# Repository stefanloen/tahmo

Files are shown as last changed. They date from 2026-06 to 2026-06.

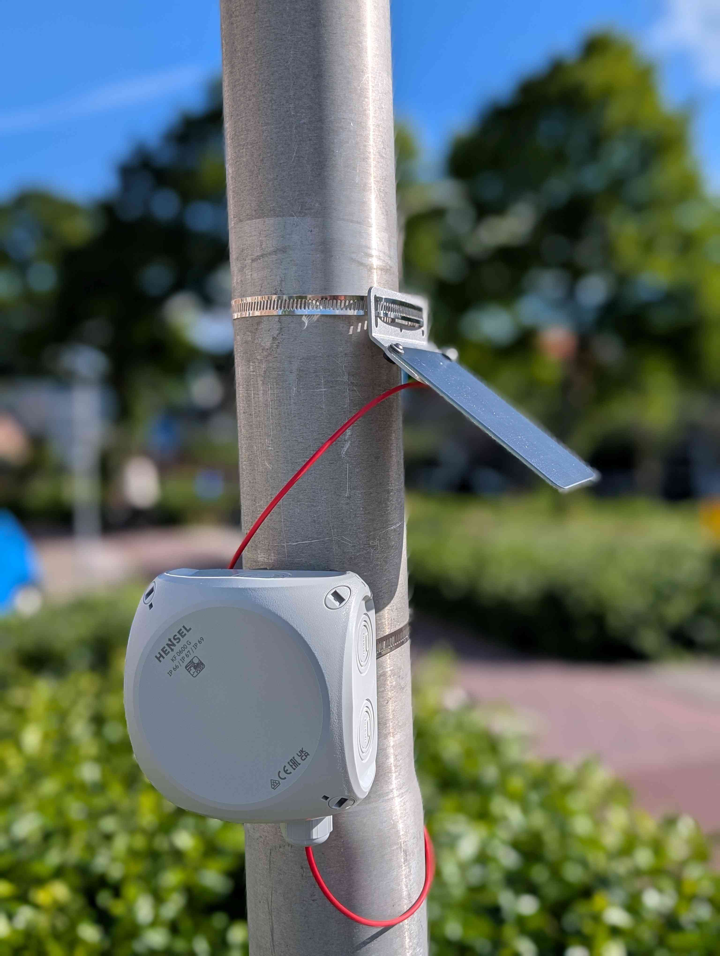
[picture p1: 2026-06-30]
docs/files/wlm.jpg

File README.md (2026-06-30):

# realtime-gnssrefl
The repository for the water level measurement system from TAHMO.

The project contains the following parts

## analysis
Provides tools for analysing GNSS date (similar to what is in the firmware).

## control
Contains the firmware for the Pico 2. For installation ensure Rust is installed and use the following commands
```bash
$ cd control
$ rustup target add thumbv8m.main-none-eabihf
```
And flash and run the firmware with the following commands:
```bash
$ cd control
$ cargo run --release
```

Creating an uf2 file:
```bash
$ picotool uf2 convert .\target\thumbv8m.main-none-eabihf\release\control -t elf control.uf2
```
## docs
Webpage tools for flashing, configuring, data viewing and documentation. Hosted at Github: [TAHMO WLM Dashboard](https://stefanloen.github.io/tahmo/)

## hardware
Contains the KiCAD PCB design files as raw project folder and as archive. Also contains some design documentation.

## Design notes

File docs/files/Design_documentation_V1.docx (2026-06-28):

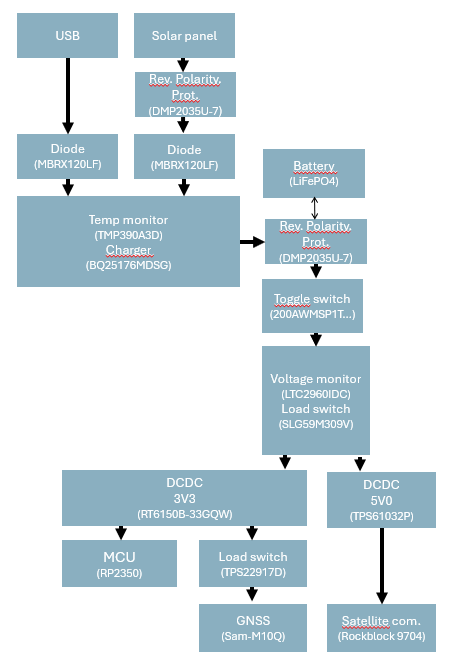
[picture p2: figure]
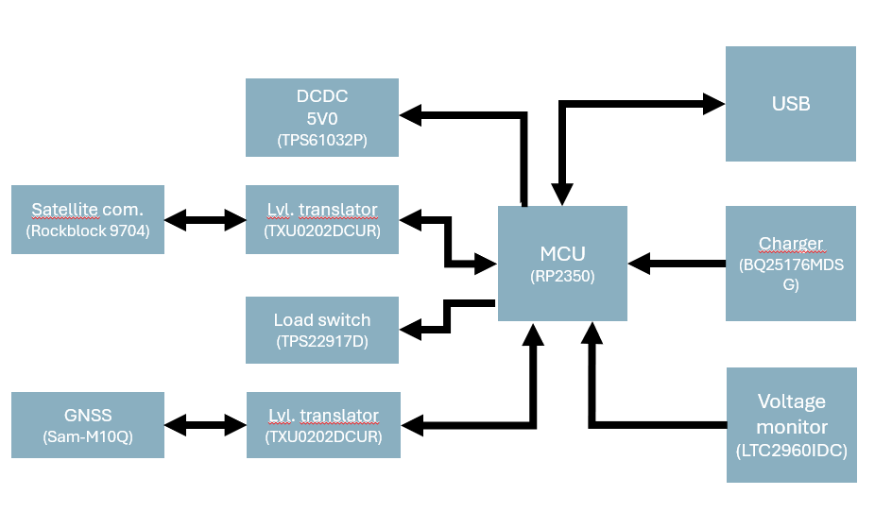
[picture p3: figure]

## Power management

### Battery

For the battery, LiFePO4 is chosen as it offers high temperature stability and long lifetime. LiFePO4 has a voltage range from 2.5V to 3.6V. A typical discharge curve looks like the following:

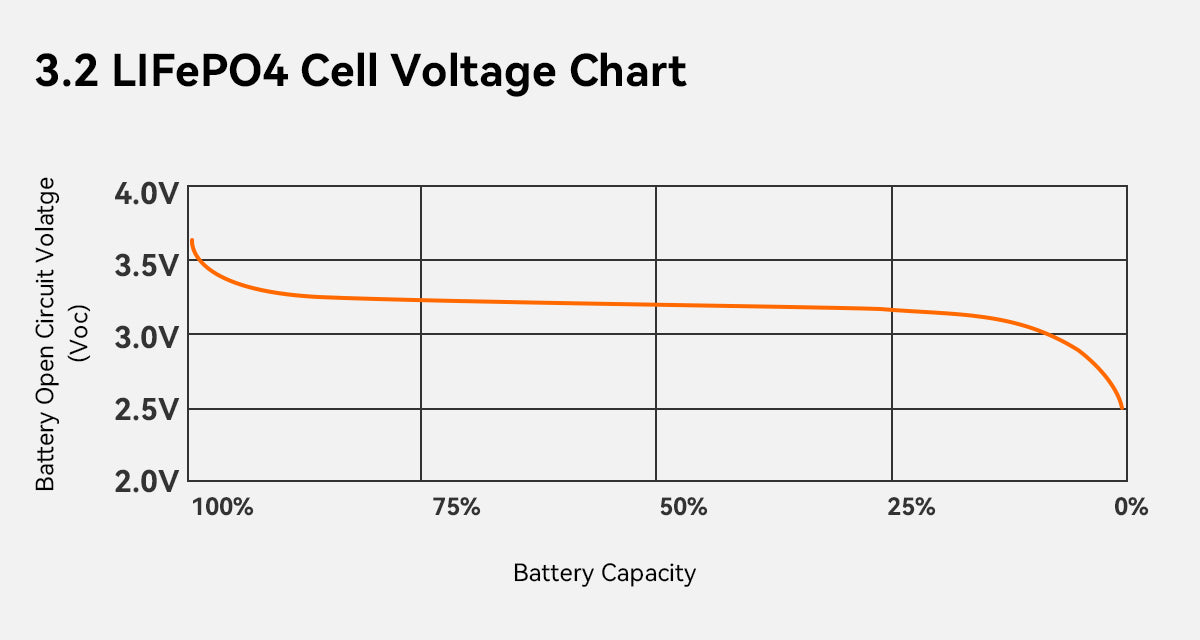
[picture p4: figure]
LiFePO4 battery voltage curve/ LFP charging curve

Battery size is 26550, which leads to roughly 3000mAh depending on manufacturer.

### Reverse polarity protector (Battery & solar panel)

To protect the system against a wrongly oriented battery, a P-channel enhancement mode mosfet is used. Inspiration from Reverse Voltage Protection With A P-FET | Hackaday (https://hackaday.com/2011/12/06/reverse-voltage-protection-with-a-p-fet/). The 5.1V Zener diode protects the gate against voltages above 5.1V. This is not necessary for battery protection, but it is for solar panel reverse voltage protection. Relevant specs are:

- Rds_on < 45mOhm (1A leads to 45mV drop, ~1% loss)
- Vgs_threshold = -0.7V (Lowest source goes is 2.5V – 1V body diode =1.5V)
- Vgs_breakdown = +-10V (Battery max is 3V6)
- Vds_breakdown = -20V (Battery max is 3V6)

Normal operation mode:

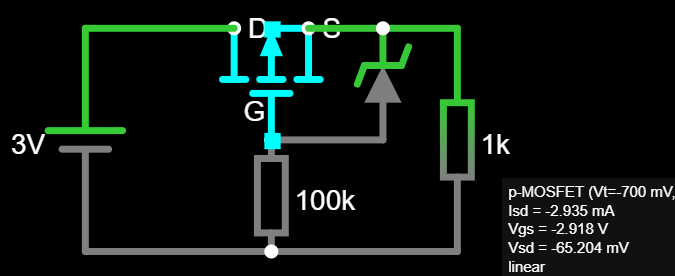
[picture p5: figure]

Reverse polarity:

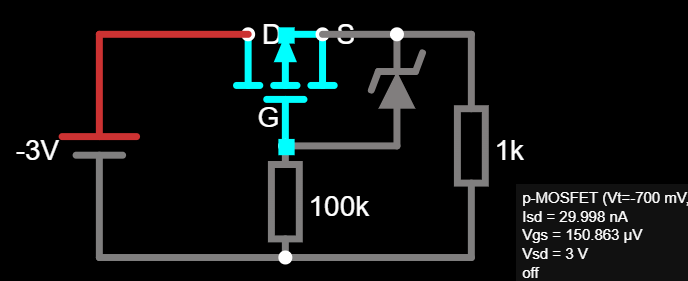
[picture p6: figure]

Charging:

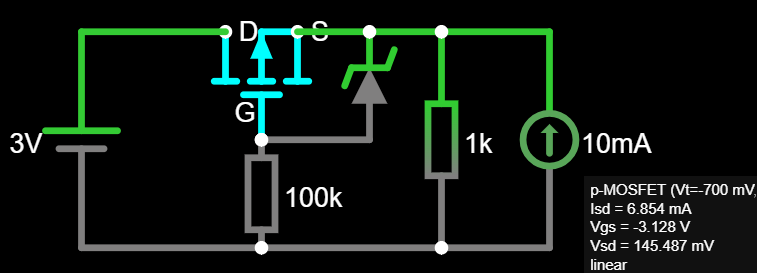
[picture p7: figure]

### Reverse polarity indicator (Battery & solar panel)

To indicate that the battery is placed in reverse polarity, we use a reverse placed LED with a resistor. Typical reverse breakdown voltage is 5V. This is good enough for battery. For solar panel, we need to use a ‘stronger’ diode in series. Inspired by: From the Q and A | Nuts & Volts Magazine (https://www.nutsvolts.com/questions-and-answers/diodes-in-series).

This design uses 1N4148W. Important specs are:

- Leakage current <1 uA
- Max Forward voltage = 1V
- Max Reverse voltage = 75V

Typical LED <0.1uA

Because the leakage current is different and unpredictable ,we need resistors in parallel to make sure the 1N4148 diode ‘carries’ all the voltage. For this we use Resistors in a higher order of magnitude so the leakage current of the diodes themselves is negligible.

10uA parallel resistors: R=U/I = 20V/10uA = 2Mohm. To give the 1N4148 90% of the voltage, we give it a parallel resistor of 1.8Mohm. The LED is given 200kOhm. Verified in Fallstad:

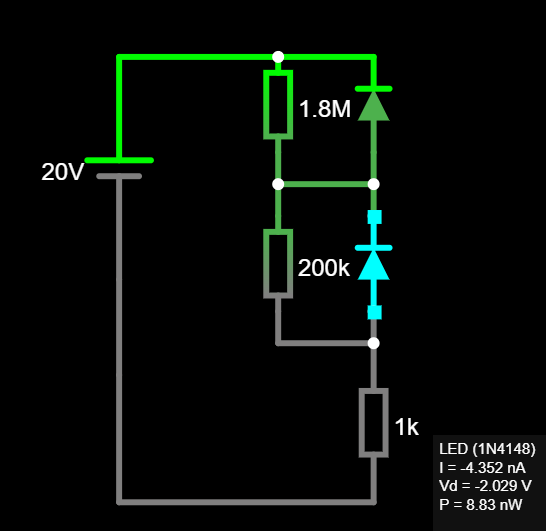
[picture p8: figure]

For practical reasons, 2.2Mohm and 220Kohm are used.

Led series resistance (18V-0.7V-0.7V)/3mA = 5.6k). A typical solar panel will give much lower current, but hopefully the LED will still be visible.

## Charging

The BQ25176M solar charger IC is used. It is particularly marketed for ‘solar harversting’ Important specifications are:

- Linear
- Battery tracking Input Voltage Dynamic Power Management (VINDPM)
- No timeout timer (Not needed)

Both solar panel and Vbus input are connected to input through a diode. MBRX120LF-TP is used. These have a ‘super low’ forward voltage drop of 0.2V. USB is open solderjumper because usb connected without battery plugged in is undefined behaviour of the BQ25176M. Caps are according to datasheet

ISET:

Icharge = 300 / Riset. 600Ohm → 500mA max charging current. With typical battery this is 0.15C.

VSET

100Kohm → 3.5V max charge voltage

/PG

Open drain Active low power good. It means the input voltage is OK. Connected to MCU. 10Kohm pullup according to datasheet. Open solderjumper to LED. R = (3.3V-0.7V) / 3mA ~= 1Kohm

STAT

Open drain Active low Charging status. 10Kohm pullup according to datasheet. Connected to MCU. Open solderjumper to LED. R = (3.3V-0.7V) / 3mA ~= 1Kohm

Bias

Bias pin is connected through 10kOhm to ground. Tolerance is unknown so 1% used. BIAS pin can be pulled down to disable charging. This is used for temperature monitoring of the battery. It is connected to the output of the programmable temperature switch TMP390A3D.

### TMP390A3D

Programmable temperature switch. Open drain active low outputs connected together. On both hot and cold trip the bias pin from the charger is pulled down. Output pins need 10kOhm pullup, but to not interfere with the bias resistor of the BQ25176M, it is not placed. This component is placed close to the GND of the batter for best heat transfer possible. 1 cap according to datasheet.

SET A

9.09 Kohm → 60 degrees hot trip

SET B

21.5 Kohm → 0 degrees cold trip. This also sets the hysteresis to 5% for both hot and cold trip.

## Undervoltage protection

After a toggle switch (200AWMSP1T2A1M2RE) a load switch (SLG59M309V) is placed to disconnect all power-draining components. If one of these switches in series is disconnected, charging via solar panel or USB still functions.

### SLG59M309V

On is connected to active low empty_bat. This is the signal coming from the voltage monitor (LTC2960IDC-1). 10nF capacitor on CAP pin → 2.5ms rise time.

### LTC2960IDC-1

Voltage monitor. Connected directly after the polarity protection. Quite specialized IC to configure programmable voltage thresholds (low battery & empty battery) and programmable hysteresis. 1 cap according to reference schematics

ADJ input below 400mV pulls RST low → open drain active low empty bat

IN+ input below 400mV pulls OUT low → open drain active low low bat

Low bat triggers at 0.4V / 49.9 x (340 + 49.9) = 3.13V

Empty bat is more complex. It has huge hysteresis to account for the voltage dip at the end of the LiFePO4 battery capacity. The 100K pull-up resistor on empty bat makes the circuit a bit more complex. Out / Lowbat does not have a pull-up resistor as this is already integrated into the MCU and performance is not critical. (So software mistake does not cause problems)

Falling threshold: 0.4V / 49.9 x (316 || (1.5M + 100k) + 49.9) = 2.51V

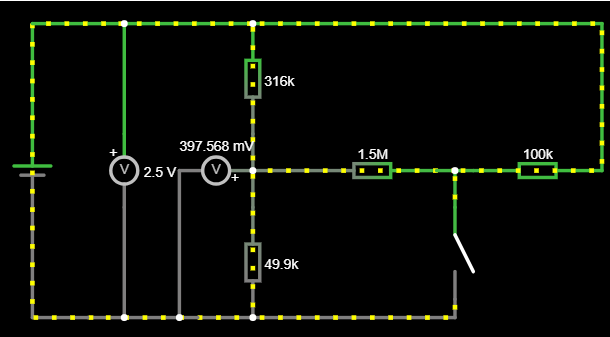
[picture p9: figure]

When empty bat is pulled low, the battery voltage must rise higher because the voltage divider used for the threshold is pulled down extra by the empty bat output. The internal hysteresis of 10mV in the voltage monitor IC is also taken into account.

Rising threshold: 0.4V / (49.9 || 1500) x ((49.9 || 1500) + 316)) = 3.09V

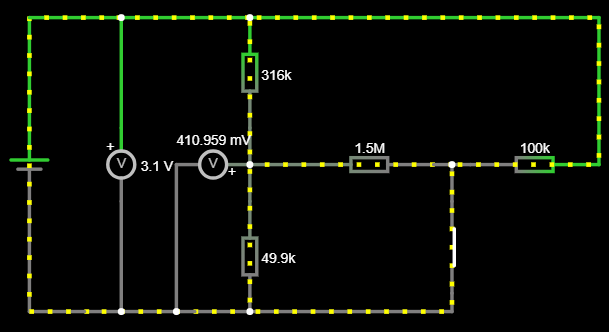
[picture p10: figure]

Values are found with Python Sympy.

RT

Connected to VCC for a 200ms reset timeout delay.

## 5V DCDC Boost convert

To create 5V from Vsys for the Rockblock, the TPS61032P is used. This seems a bit overkill, as it can supply 4A from 1.8V input. The Rockblock draws 500mA according to datasheet However, tests have shown (at least, the hypothesis is) that the input spike it draws is much higher. This caused problems in the prototype. Therefore, the 5V DCDC in this design is comfortably overkill.

For the inductor, CDRH124–6R8 is used according to datasheet (max power solution)

Vbat has 20uF cap (10uF is max power solution)

Output cap is 220uF tantalum low esr with a 2.2uF X5R capacitor (both from max power solution). An extra slot is available to double the capacitance if necessary.

LBI & LBO

Can be used for low battery indication. Unused. LBI is connected to GND as it cannot be left floating.

SYNC

Power save mode is disabled through Closed solderjumper by connecting SYNC to VSYS

TPS22917DBV

EN

Enables the DCDC. Connected to MCU. Pulled down with 100k

FB

Only used for adjustable versions. The TPS61032P is fixed at 5V

## 3V3 DCDC Buck boost converter

The RT6150B-33GQW creates 3V3 from the Vsys. It has to be buck boost as VSYS swings around 3V2. This DCDC is always on as it powers the mcu. Caps overspecced according to datasheet. Inductor according to datasheet.

FB

Connected to VOUT for non-adjustable versions

PS

Power save mode connected to GND through closed solderjumper to enable power save mode operation.

## GNSS load switch

To enable the GNSS, the SLG59M309V (Same as for battery undervoltage lockout) is used. Previously, the TPS22917 was used, but its replaced by this IC for the sole reason of less different components. Connections same as other SLG59M309V

## GNSS

The SAM-M10Q is used. This has also been used in the prototype. No requirements on caps.

Timepulse

Can be enabled by soldering the jumpersolder, this enables a blinking orange LED when GNSS signals are received. Max 2mA according to datasheet. R = (3.3V-0.7) / 2mA = 1.3kOhm. 2kOhm used.

EXTINT

No reason to use, but connected to MCU anyway with open solderjumper.

SAFEBOOT & RESET & SDA & SCL

Unused

RXD & TXD

Uart is used for communication with the MCU. Tests have show that the gnss is backpowered through UART when VCC is off. This is prevented by using a Level translator.

### Level translator

TXU0202DCUR is used to protect the gnss module (and the rockblock) against backpowering. Caps according to datasheet.

OE

Output enable. Enabled by the same signal that turns the load switch (or 5Vdcdc for rockblock) on, coming from the MCU. When disabled all outputs are isolated.

## Satellite communication

The rockblock 9704 is a standalone module that is used to connect with the Iridium network. The following pins are used:

I_EN

Enables the module

I_BTD

Signals to the MCU that the supercapacitor is charged

I_WK_I / I_WK_O

Unused but connected so MCU anyway for later wake functionality

TXD / RXD

Uart, also connected through TXU0202DCUR

## USB

USB-C connector is used. According to Universal Serial Bus Type-C Cable and

Connector Specification, release 2:

CC1 and CC2:

Need 5.1k pull-down (p. 236) 1% tolerance just to be sure

VBUS:

Max capacitance = 10uF (p. 234)

## MCU

The RP2350A is used. This was also used on the prototype with a Raspberry Pi Pico 2. All design according to schematic followed from Raspberry Pi Pico 2 Datasheet: An RP2350-based microcontroller board. (https://pip-assets.raspberrypi.com/categories/1005-raspberry-pi-pico-2/documents/RP-008299-DS-2-pico-2-datasheet.pdf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) Layout rules followed from this guideline: Hardware design with RP2350: Using RP2350 microcontrollers to build boards and products. (https://pip-assets.raspberrypi.com/categories/1214-rp2350/documents/RP-008280-DS-1-hardware-design-with-rp2350.pdf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)

Voltage regulator layout guidelines are strictly followed. AOTA-B201610S3R3-101-T Inductor is used.

### Watchdog

To enable low power savings and watchdog functionality, the TPL5010 is used. The configuration is in such a manner that it signals the MCU every ~60seconds. The MCU must respond with DONE. If the MCU fails to do so, it pulls the RST pin low which is connected to the RUN pin of the MCU. RST has a pullup. Cap according to spec.

Delay

The delay resistor is set to 22.1Kohm which corresponds to roughly 1 minute. This means the wake signal is given every minute. This way, it can also be used to sleep for 1 minute.

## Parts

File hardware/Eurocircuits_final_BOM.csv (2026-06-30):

Reference: | E1789734
Date: | Tue Jun 30 2026 15:51:00 GMT+0200 (Midden-Europese zomertijd)
Generated by: | Eurocircuits PCBA Visualizer
Reference designators | Quantity | MPN | Manufacturer | Description
C1, C2, C3, C4, C12, C13, C14, C15, C16, C18, C20, C22, C23, C26, C29 | 15 | GPC0603104-25 | Generic part | 0.1µF ±10% 25V Ceramic Capacitor X7R 0603 (1608 Metric)
C32, C33 | 2 | GPC0603104-25 | Generic part | 0.1µF ±10% 25V Ceramic Capacitor X7R 0603 (1608 Metric)
C5 | 1 | GPC0805106-25 | Generic part | 10µF ±10% 25V Ceramic Capacitor X5R 0805 (2012 Metric)
C6, C7 | 2 | GPC1210476-16 | Generic part | 47µF ±20% 16V Ceramic Capacitor X5R 1210 (3225 Metric)
C8 | 1 | GPC0805225-25-X7R | Generic part | 2.2µF ±10% 25V Ceramic Capacitor X7R 0805 (2012 Metric)
C11, C36 | 2 | GPC0603103 | Generic part | 10000pF ±10% 50V Ceramic Capacitor X7R 0603 (1608 Metric)
C17, C25, C31 | 3 | GPC0603475-10 | Generic part | 4.7µF ±10% 10V Ceramic Capacitor X5R 0603 (1608 Metric)
C19, C21, C24 | 3 | GPC0402475-6.3 | Generic part | 4.7µF ±20% 6.3V Ceramic Capacitor X5R 0402 (1005 Metric)
C27, C30 | 2 | GPC0603150 | Generic part | 15pF ±5% 50V Ceramic Capacitor C0G, NP0 0603 (1608 Metric)
C28 | 1 | GPC0603102-25 | Generic part | 1000pF ±10% 25V Ceramic Capacitor X7R 0603 (1608 Metric)
C34, C35 | 2 | GPC0603105 | Generic part | 1µF ±10% 50V Ceramic Capacitor X5R 0603 (1608 Metric)
R1 | 1 | GPR06032K | Generic part | 0603, Res 2.0kOhm, 75V, 1.0%, 100mW
R2, R3 | 2 | GPR06035K1 | Generic part | 0603, Res 5.1kOhm, 75V, 1.0%, 100mW
R4, R5, R17, R26, R32, R36 | 6 | GPR0603100K | Generic part | 0603, Res 100.0kOhm, 50V, 1.0%, 100mW
R37 | 1 | GPR0603100K | Generic part | 0603, Res 100.0kOhm, 50V, 1.0%, 100mW
R18, R19 | 2 | GPR0603100K | Generic part | 0603, Res 100.0kOhm, 50V, 1.0%, 100mW
R6, R7 | 2 | GPR060327R | Generic part | 0603, Res 27.0Ohm, 75V, 1.0%, 100mW
R8 | 1 | GPR040233R | Generic part | 0402, Res 33.0Ohm, 50V, 1.0%, 62.5mW
R9 | 1 | GPR0603200R | Generic part | 0603, Res 200.0Ohm, 50V, 1.0%, 100mW
R10 | 1 | GPR060322K | Generic part | 0603, Res 22.0kOhm, 50V, 1.0%, 100mW
R11, R12, R15, R35, R40, R41 | 6 | GPR06031K | Generic part | 0603, Res 1.0kOhm, 50V, 1.0%, 100mW
R16, R20 | 2 | GPR06031K | Generic part | 0603, Res 1.0kOhm, 50V, 1.0%, 100mW
R13, R14 | 2 | GPR0603100R | Generic part | 0603, Res 100.0Ohm, 50V, 1.0%, 100mW
R21 | 1 | GPR06039K1 | Generic part | 0603, Res 9.1kOhm, 75V, 1.0%, 100mW
R23 | 1 | GPR06032M2 | Generic part | 0603, Res 2.2MOhm, 75V, 1.0%, 100mW
R24 | 1 | GPR0603220K | Generic part | 0603, Res 220.0kOhm, 75V, 1.0%, 100mW
R25 | 1 | GPR06035K6 | Generic part | 0603, Res 5.6kOhm, 50V, 1.0%, 100mW
R31 | 1 | GPR06031M5 | Generic part | 0603, Res 1.5MOhm, 75V, 1.0%, 100mW
R33 | 1 | GPR0603620R | Generic part | 0603, Res 620.0Ohm, 75V, 1.0%, 100mW
R34 | 1 | GPR060310K | Generic part | 0603, Res 10.0kOhm, 50V, 1.0%, 100mW
R38, R39 | 2 | GPR060310K | Generic part | 0603, Res 10.0kOhm, 50V, 1.0%, 100mW
D1, D12 | 2 | LTST-C191KFKT | Lite-On | Orange 605nm LED Indication - Discrete 2V 0603 (1608 Metric)
D2, D6, D10 | 3 | LTST-C193KRKT-5A | Lite-On | Red 631nm LED Indication - Discrete 2V 0603
D3, D11 | 2 | LTST-C193KGKT-5A | Lite-On | Green 572nm LED Indication - Discrete 2V 0603 (1608 Metric)
D4 | 1 | LTST-C190TBKT | Lite-On | Blue 470nm LED Indication - Discrete 3.3V 0603 (1608 Metric)
D5 | 1 | 1N4148W | Vishay | Small Signal Fast Switching Diode SOD-123 SMD DIODE 75V /125mA
D7 | 1 | BZT52C5V6-7-F | Diodes Inc. | Zener Diode 5.6V 500mW ±7% Surface Mount SOD-123
J5 | 1 | 691213510002 | Wurth Elektronik | 2 Position Wire to Board Terminal Block Horizontal with Board 0.200" (5.08mm) Through Hole
L1 | 1 | 74479276222C | Wurth Elektronik | 2.2µH Shielded Molded Inductor 1.6A 135 mOhm Max 0806 (2016 Metric)
R28, R30 | 2 | RC0603FR-0749K9L | Yageo | RES 49.9K OHM 1% 1/10W 0603
BT1 | 1 | Keystone_1106 | Keystone Electronics | Battery Holder 26650 1 Cell SMD (SMT) Tab
C9 | 1 | TR3E227M016C0100 | Vishay Sprague | 220 µF ±20% Molded Tantalum Capacitors 16 V 2917 (7343 Metric) 100mOhm @ 100kHz
D8, D9 | 2 | MBR120LSFT1G | ON Semiconductor | Diode Schottky 20V 1A Surface Mount SOD-123L
IC1, IC2 | 2 | TXU0202DCUR | Texas Instruments | Two channel fixed-direction level shifter with channels in opposite direction 8-VSSOP -40 to 125
IC3 | 1 | RT6150B-33GQW | Richtek USA Inc. | Buck-Boost Switching Regulator IC Positive Fixed 3.3V 1 Output 800mA 10-WFDFN Exposed Pad
IC4 | 1 | TPS61032PWPR | Texas Instruments | Boost Switching Regulator IC Positive Fixed 5V 1 Output 3.6A (Switch) 16-PowerTSSOP (0.173", 4.40mm Width)
IC5, IC10 | 2 | SLG59M309V | Renesas | Power Switch/Driver 1:1 N-Channel 4A 8-FC-TDFN (1.5x2)
IC6 | 1 | RP2350A-CT | Raspberry Pi | MCU, 32 bit, ARM Cortex-M33F, 150 MHz, 520 KB RAM, QFN-60
IC7 | 1 | W25Q32RVXHJQ TR | Winbond Electronics | Serial NOR Flash, QSPI, 32MBit, 8-pin USON 2x3mm 133MHz
IC8 | 1 | LTC2960IDC-1#TRMPBF | Analog Devices | Supervisor Open Drain or Open Collector 2 Channel 8-DFN (2x2)
IC9 | 1 | TMP390A3DRLR | Texas Instruments | Thermostat Programmable Active Low Open Drain
J1 | 1 | ESW-108-58-S-D | Samtec | 16 Position Elevated Socket Connector 0.100" (2.54mm) Through Hole Gold
J2 | 1 | 2193200001 | Molex | USB-C (USB TYPE-C) USB 2.0 Receptacle Connector 24 (16+8 Dummy) Position Surface Mount, Through Hole
L2 | 1 | CDRH124NP-6R8MC | Sumida | 6.8 µH Shielded Inductor 4.9 A, ±20%, 23mOhm Max Nonstandard
L3 | 1 | AOTA-B201610S3R3-101-T | Abracon | 3.3 µH ±20% Shielded Molded Inductor 2.1 A 140mOhm Max 0806 (2016 Metric)
Q1, Q2 | 2 | DMP2035U-7 | Diodes Inc. | Transistor, P-Channel Enhancement Mode MOSFET, SMD
R22 | 1 | RMCF0603FT21K5 | Stackpole Electronics | 21.5 kOhms ±1% 0.1W, 1/10W Chip Resistor 0603 (1608 Metric) Automotive AEC-Q200 Thick Film
R27 | 1 | RT0603DRE07340KL | Yageo | 340 kOhms ±0.5% 0.1W, 1/10W Chip Resistor 0603 (1608 Metric) Thin Film
R29 | 1 | RMCF0603FT316K | Stackpole Electronics | 316 kOhms ±1% 0.1W, 1/10W Chip Resistor 0603 (1608 Metric) Automotive AEC-Q200 Thick Film
S1 | 1 | PTS810SJK250SMTRLFS | C&K Components | Tactile Switch SPST-NO Top Actuated Surface Mount
S2 | 1 | 200AWMSP1T2A1M2RE | E-Switch | Toggle Switch SPDT Through Hole
U1 | 1 | SAM-M10Q-00B | U-Blox | - RF Receiver Galileo, GLONASS, GPS 1.575GHz, 1.602GHz -165dBm 400kbps On-Board, Patch Module
U2 | 1 | TPL5010DDCR | Texas Instruments | Programmable Timer IC TSOT-23-6
U3 | 1 | BQ25176MDSGR | Texas Instruments | 800-mA linear battery charger for one-cell Li-ion and LiFePO4 with VINDPM 8-WSON -40 to 125
Y1 | 1 | ABM8-272-T3 | Abracon | 12 MHz ±30ppm Crystal 10 pF 50 Ohms 4-SMD, No Lead

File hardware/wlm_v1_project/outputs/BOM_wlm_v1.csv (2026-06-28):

Id | Designator | Footprint | Quantity | Designation | Supplier and ref
1 | BT1 | 26650_holder | 1 | Keystone 1106
2 | C1, C2, C3, C4, C12, C13, C14, C15, C16, C18, C20, C22, C23, C26, C29 | C_0603_1608Metric | 15 | 100n X5R 6.3V 10%
3 | C5 | C_0805_2012Metric | 1 | 22u X5R 16V 20%
4 | C6, C7 | C_1210_3225Metric | 2 | 47u X5R 10V 20%
5 | C8 | C_0805_2012Metric | 1 | 2u2 X5R 16V 10%
6 | C9 | CAPPM7343X430N | 1 | TR3E227M016C0100
7 | C11, C36 | C_0603_1608Metric | 2 | 10n X5R 10V
8 | C17, C25, C31 | C_0603_1608Metric | 3 | 4u7 6.3V X5R 20%
9 | C19, C21, C24 | C_0402_1005Metric | 3 | 4u7 6.3V X5R 20%
10 | C27, C30 | C_0603_1608Metric | 2 | 15p 25V C0G 5%
11 | C28 | C_0603_1608Metric | 1 | 1n X7R 25V 10%
12 | C32, C33 | C_0603_1608Metric | 2 | 100n X5R 10V
13 | C34, C35 | C_0603_1608Metric | 2 | 1uF X5R 35V
14 | D1, D12 | LED_0603_1608Metric | 2 | Led Orange 5mA
15 | D2, D6, D10 | LED_0603_1608Metric | 3 | Led Red 5mA
16 | D3, D11 | LED_0603_1608Metric | 2 | Led Green 5mA
17 | D4 | LED_0603_1608Metric | 1 | Led blue 5mA
18 | D5 | D_SOD-123 | 1 | 1N4148W
19 | D7 | D_SOD-123 | 1 | 5.6V Zener
20 | D8, D9 | SOD3716X135N | 2 | MBRX120LF-TP
21 | IC1, IC2 | SOP50P310X90-8N | 2 | TXU0202DCUR
22 | IC3 | SON50P250X250X80-11N-D | 1 | RT6150B-33GQW
23 | IC4 | SOP65P640X120-17N | 1 | TPS61032PWP
24 | IC5, IC10 | SLG59M309V | 2 | SLG59M309V
25 | IC6 | QFN40P700X700X90-61N-D | 1 | RP2350A-CT
26 | IC7 | SON50P300X200X40-9N | 1 | W25Q32RVXHJQ
27 | IC8 | SON45P200X200X80-9N-D | 1 | LTC2960IDC-1#TRMPBF
28 | IC9 | SOTFL50P160X60-6N | 1 | TMP390A3DRLR
29 | J1 | Rockblock_9704 | 1 | ESW-108-58-S-D
30 | J2 | 2193200001 | 1 | 219320-0001
31 | J5 | TerminalBlock_Phoenix_MKDS-1,5-2-5.08_1x02_P5.08mm_Horizontal | 1 | Screw_Terminal_01x02
32 | L1 | L_Wuerth_PMFI-201610 | 1 | 2u2 10% (74479276222C)
33 | L2 | CDRH124NP-6R8MC | 1 | CDRH124NP-6R8MC
34 | L3 | AOTAB201610S3R3101T | 1 | AOTA-B201610S3R3-101-T
35 | Q1, Q2 | DMP2035U7 | 2 | DMP2035U-7
36 | R1 | R_0603_1608Metric_Pad0.98x0.95mm_HandSolder | 1 | 2k 10%
37 | R2, R3 | R_0603_1608Metric_Pad0.98x0.95mm_HandSolder | 2 | 5.1k 1%
38 | R4, R5, R17, R26, R32, R36 | R_0603_1608Metric_Pad0.98x0.95mm_HandSolder | 6 | 100k 20%
39 | R6, R7 | R_0603_1608Metric_Pad0.98x0.95mm_HandSolder | 2 | 27R 50mW 1%
40 | R8 | R_0402_1005Metric_Pad0.72x0.64mm_HandSolder | 1 | 33R 63mW 1%
41 | R9 | R_0603_1608Metric_Pad0.98x0.95mm_HandSolder | 1 | 200R 63mW 1%
42 | R10 | R_0603_1608Metric_Pad0.98x0.95mm_HandSolder | 1 | 22k1 50mW 1%
43 | R11, R12, R15, R35, R40, R41 | R_0603_1608Metric_Pad0.98x0.95mm_HandSolder | 6 | 1k 10%
44 | R13, R14 | R_0603_1608Metric_Pad0.98x0.95mm_HandSolder | 2 | 100R 50mW 1%
45 | R16, R20 | R_0603_1608Metric_Pad0.98x0.95mm_HandSolder | 2 | 1k 50mW 1%
46 | R18, R19 | R_0603_1608Metric_Pad0.98x0.95mm_HandSolder | 2 | 100k 50mW 1%
47 | R21 | R_0603_1608Metric_Pad0.98x0.95mm_HandSolder | 1 | 9k09 1% 100 ppm/°C
48 | R22 | R_0603_1608Metric_Pad0.98x0.95mm_HandSolder | 1 | 21k5 1% 100 ppm/°C
49 | R23 | R_0603_1608Metric_Pad0.98x0.95mm_HandSolder | 1 | 2M2 20%
50 | R24 | R_0603_1608Metric_Pad0.98x0.95mm_HandSolder | 1 | 220k 20%
51 | R25 | R_0603_1608Metric_Pad0.98x0.95mm_HandSolder | 1 | 5k6 10%
52 | R27 | R_0603_1608Metric_Pad0.98x0.95mm_HandSolder | 1 | 340k 1%
53 | R28, R30 | R_0603_1608Metric_Pad0.98x0.95mm_HandSolder | 2 | 49k9 1%
54 | R29 | R_0603_1608Metric_Pad0.98x0.95mm_HandSolder | 1 | 316k 1%
55 | R31 | R_0603_1608Metric_Pad0.98x0.95mm_HandSolder | 1 | 1M5 1%
56 | R33 | R_0603_1608Metric_Pad0.98x0.95mm_HandSolder | 1 | 600R 1%
57 | R34 | R_0603_1608Metric_Pad0.98x0.95mm_HandSolder | 1 | 10k 1%
58 | R37 | R_0603_1608Metric_Pad0.98x0.95mm_HandSolder | 1 | 100k 1% <200 ppm/ºC
59 | R38, R39 | R_0603_1608Metric_Pad0.98x0.95mm_HandSolder | 2 | 10k 20%
60 | S1 | PTS810SJK250SMTRLFS | 1 | PTS810SJK250SMTR_LFS
61 | S2 | 200AWMSP1T2A1M2RE | 1 | 200AWMSP1T2A1M2RE
62 | U1 | ublox_SAM-M10Q | 1 | SAM-M10Q
63 | U2 | SOT-23-6 | 1 | TPL5010
64 | U3 | WSON_MDSGR_TEX | 1 | BQ25176MDSGR
65 | Y1 | ABM8272T3 | 1 | ABM8-272-T3

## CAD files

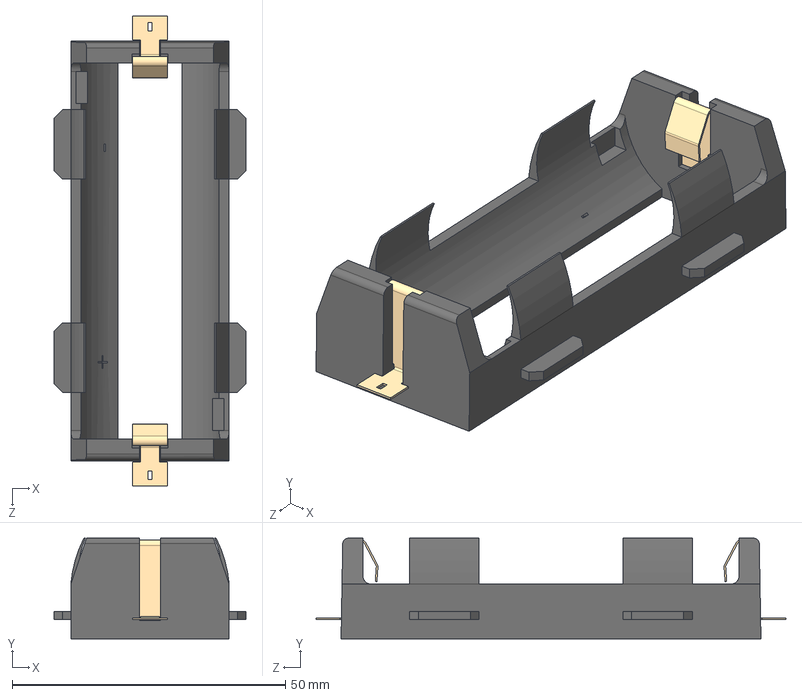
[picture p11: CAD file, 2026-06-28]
hardware/wlm_v1_project/3d_models/1106.stp
35.1 x 18.4 x 86.0 mm

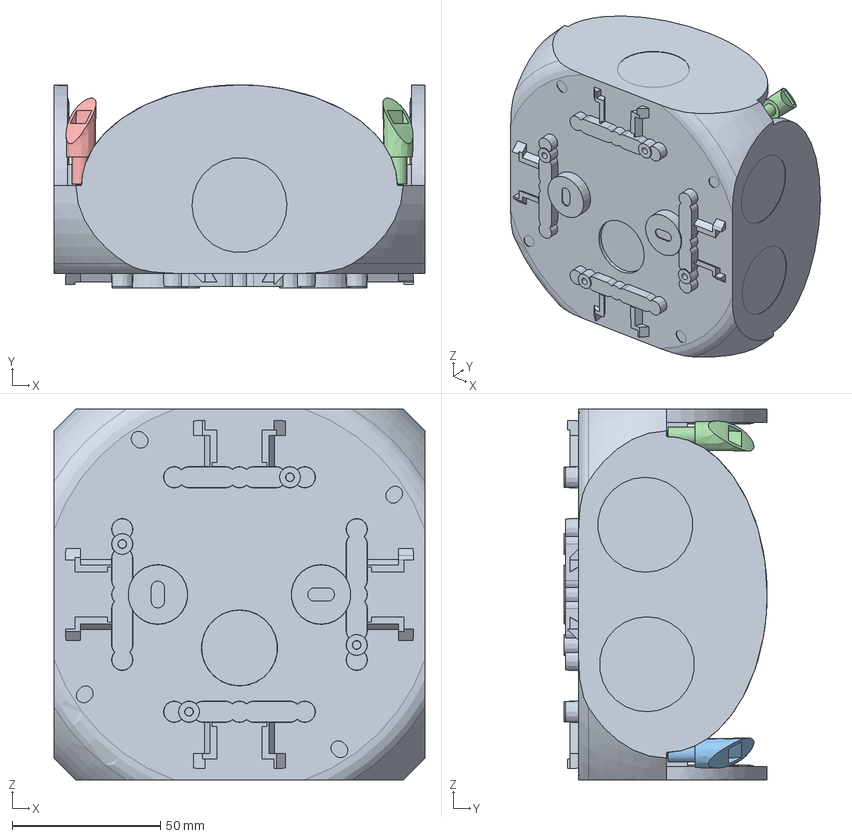
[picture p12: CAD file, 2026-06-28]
hardware/wlm_v1_project/freecad/Size_comparison.FCStd
125.0 x 68.5 x 125.0 mm
V_62520070_00
V_62520023_00
V_62520023_001
V_62520023_002
V_62520023_003
C_0603_1608Metric
PinHeader_1x01_P2.54mm_Vertical
C_0603_1608Metric001
BODY-SOT
C_0603_1608Metric002
LED_0603_1608Metric
R_0603_1608Metric
R_0603_1608Metric001
BODY-VSSOP
LEAD-VSSOP
LEAD-VSSOP001
LEAD-VSSOP002
LEAD-VSSOP003
LEAD-VSSOP004
LEAD-VSSOP005
LEAD-VSSOP006
LEAD-VSSOP007
R_0603_1608Metric002
AOTA-B201610S3R3-101-T
BODY-TSSOP
LEAD-TSSOP
LEAD-TSSOP001
LEAD-TSSOP002
LEAD-TSSOP003
LEAD-TSSOP004
LEAD-TSSOP005
LEAD-TSSOP006
LEAD-TSSOP007
LEAD-TSSOP008
LEAD-TSSOP009
LEAD-TSSOP010
LEAD-TSSOP011
LEAD-TSSOP012
LEAD-TSSOP013
LEAD-TSSOP014
LEAD-TSSOP015
DAP
ï¿½ï¿½1
ï¿½ï¿½2
ï¿½ï¿½003
C_0603_1608Metric003
ThermalPin
PinsArrayLR
PinsArrayLR001
PinsArrayLR002
PinsArrayLR003
PinsArrayLR004
PinsArrayLR005
PinsArrayLR006
PinsArrayLR007
PinsArrayLR008
PinsArrayLR009
R_0603_1608Metric003
R_0603_1608Metric004
C_0603_1608Metric004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

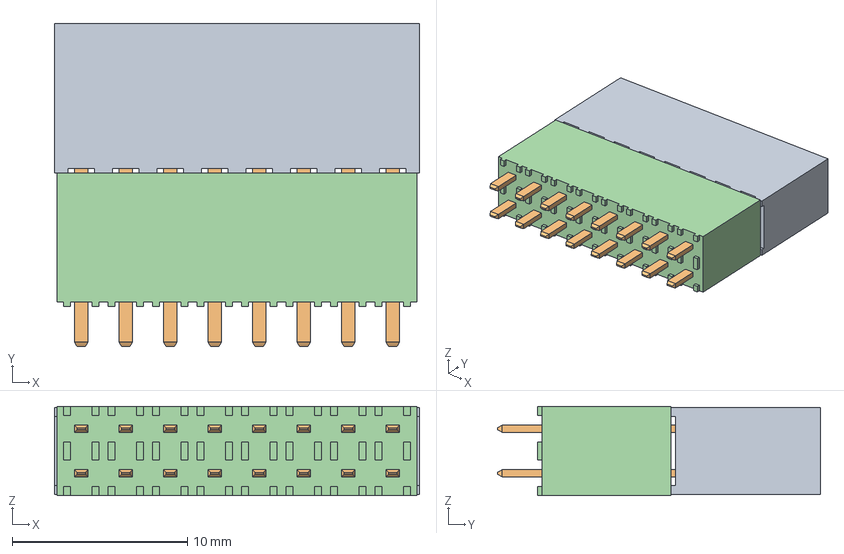
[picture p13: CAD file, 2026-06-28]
hardware/wlm_v1_project/3d_models/ESW-108-58-G-D.stp
20.8 x 18.4 x 5.08 mm
ESW-108-58-G-D_socket
ESW-108-58-G-D_pins
ESW-108-58-G-D2_PINS
ESW-108-58-G-D_bsocket

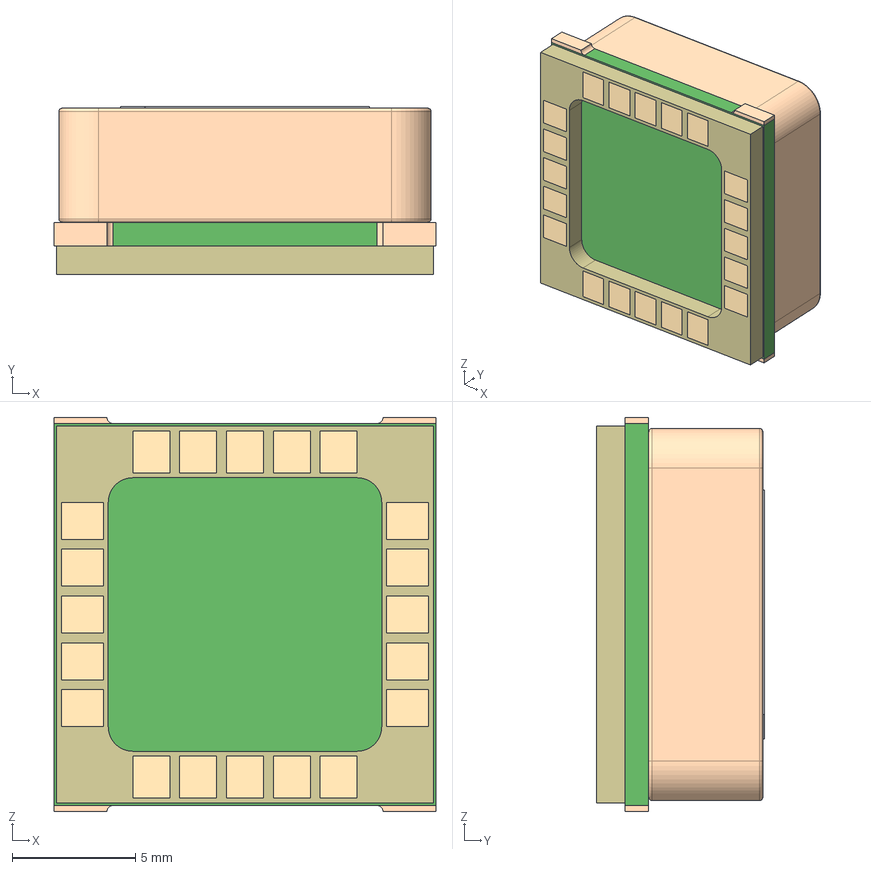
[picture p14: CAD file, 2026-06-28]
hardware/wlm_v1_project/3d_models/SAM-M10Q-00B_v1.step
15.5 x 6.80 x 16.0 mm

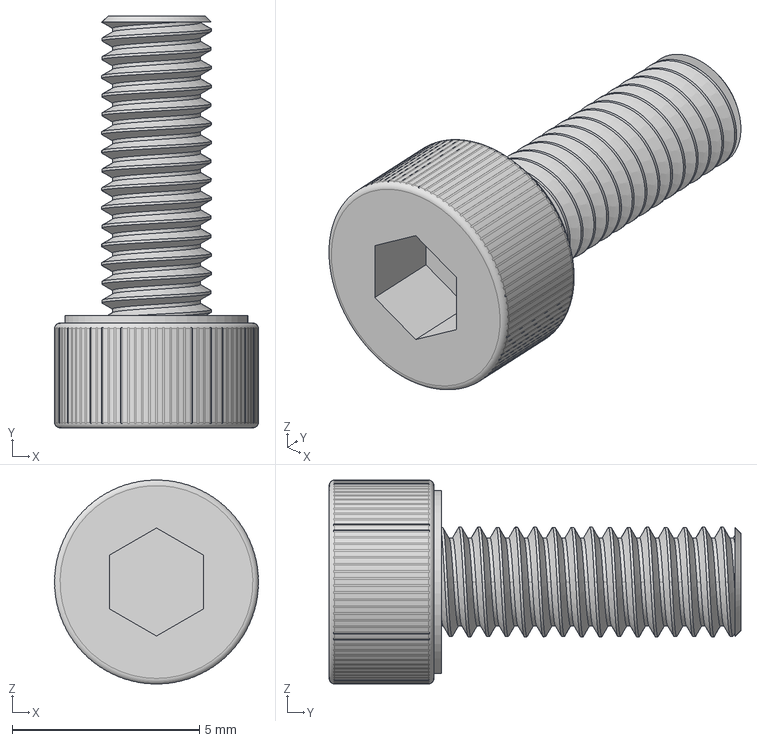
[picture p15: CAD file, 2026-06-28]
hardware/wlm_v1_project/3d_models/CHC M3 L8.step
5.45 x 11.0 x 5.45 mm

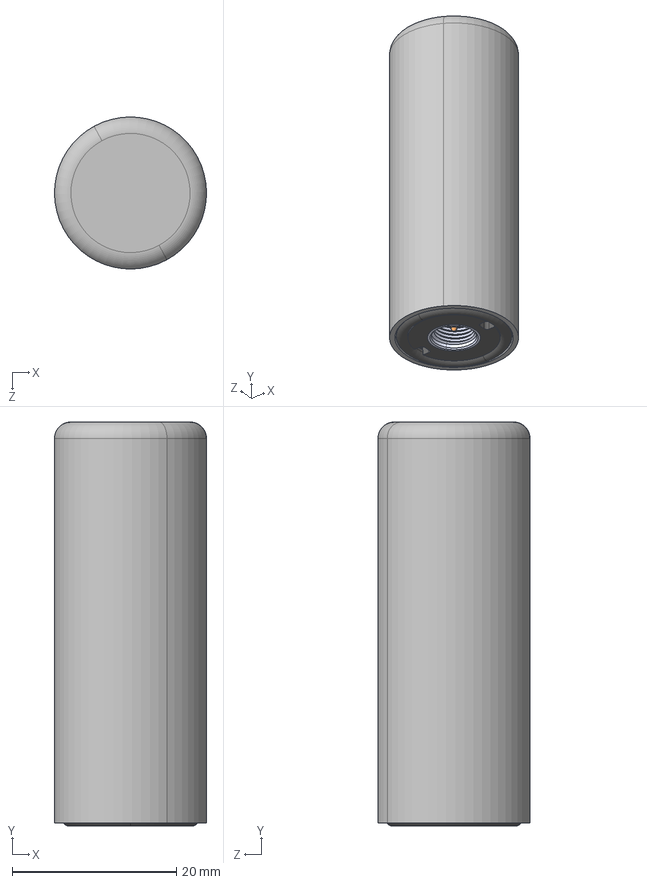
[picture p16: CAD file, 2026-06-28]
hardware/wlm_v1_project/3d_models/100-00003-02_RevB.STEP
18.5 x 49.2 x 18.5 mm
241-00003-05_View 1
178-00001-01_4.90mm LG x 4

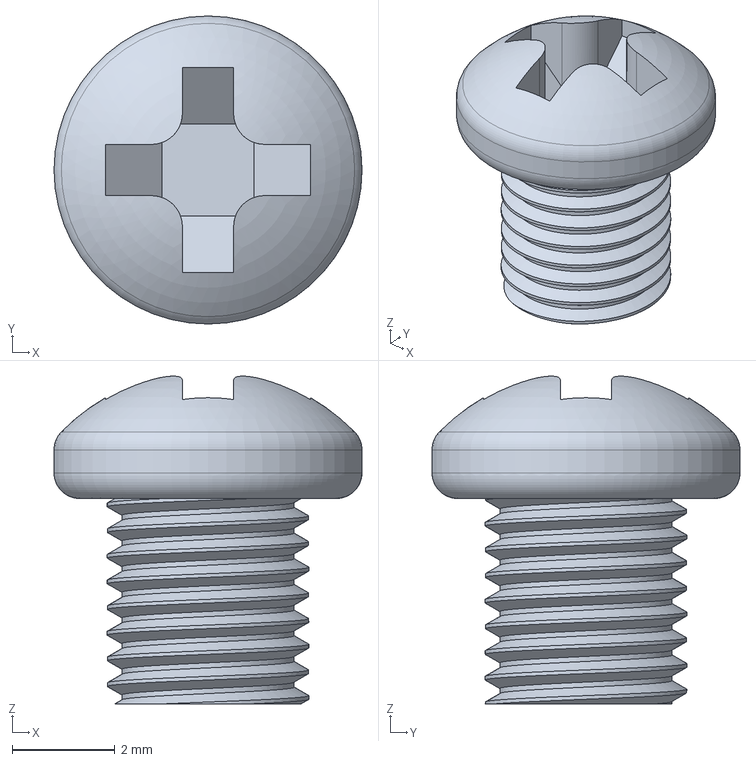
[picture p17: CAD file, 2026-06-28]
hardware/wlm_v1_project/3d_models/M4 x 4mm.step
6.00 x 6.00 x 6.38 mm

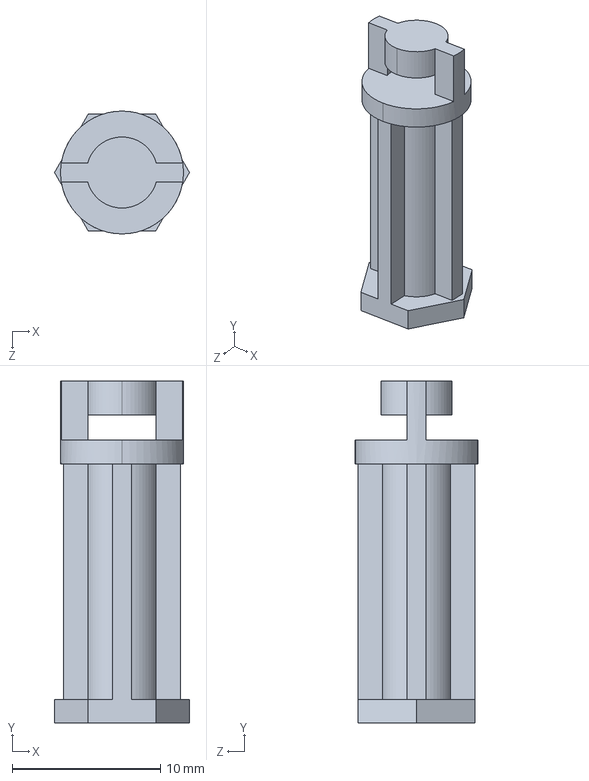
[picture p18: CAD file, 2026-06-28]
hardware/wlm_v1_project/3d_models/10035726.step
9.12 x 23.1 x 8.30 mm

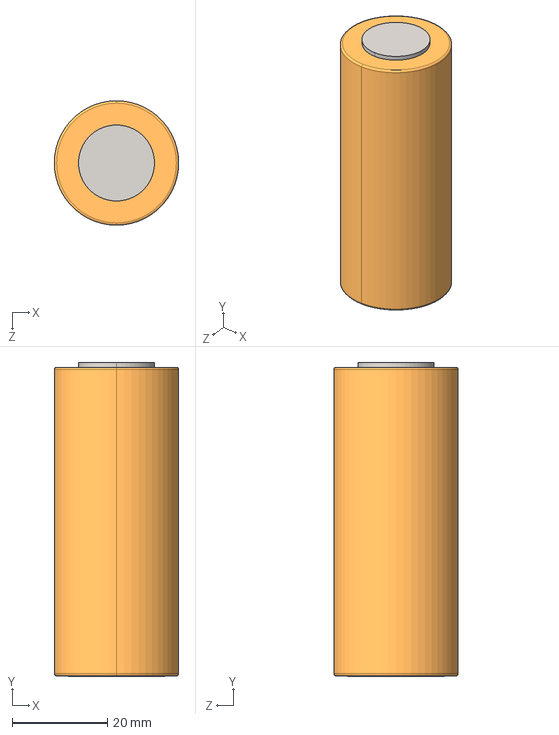
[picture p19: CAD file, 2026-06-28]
hardware/wlm_v1_project/3d_models/26650 Li-ion.STEP
26.2 x 66.1 x 26.2 mm

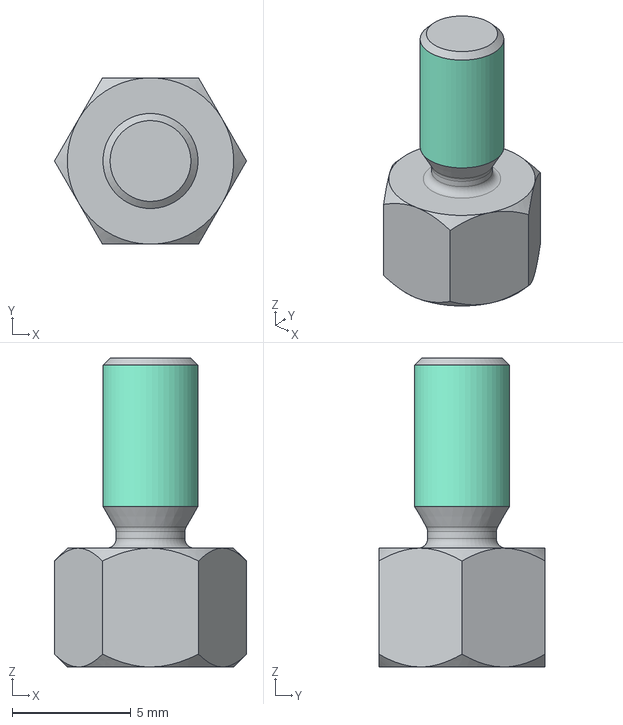
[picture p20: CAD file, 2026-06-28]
hardware/wlm_v1_project/3d_models/971050474.stp
8.08 x 7.00 x 13.0 mm

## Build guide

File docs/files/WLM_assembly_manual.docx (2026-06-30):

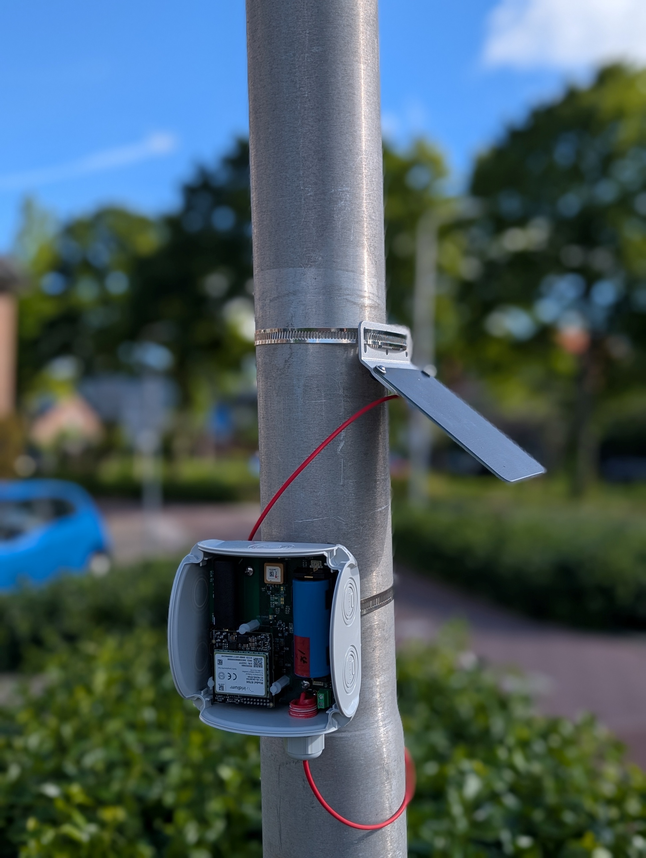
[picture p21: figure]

# WLM Assembly Manual

## TAHMO Water Level Monitor system

# Component overview

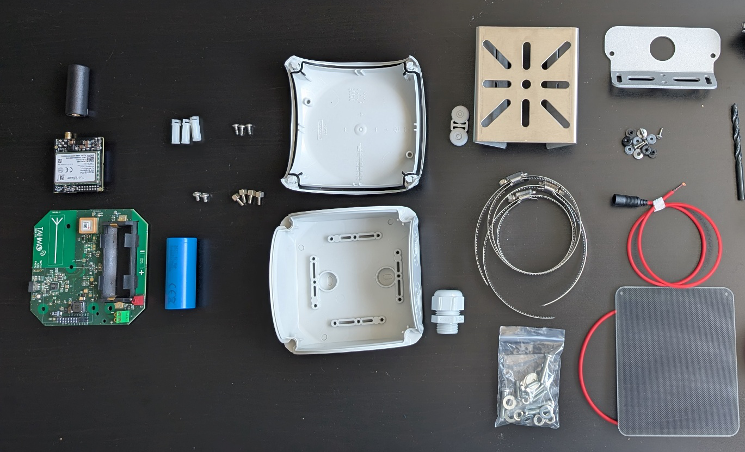
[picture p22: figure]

# Assembly WLM device

Remove one knockout.

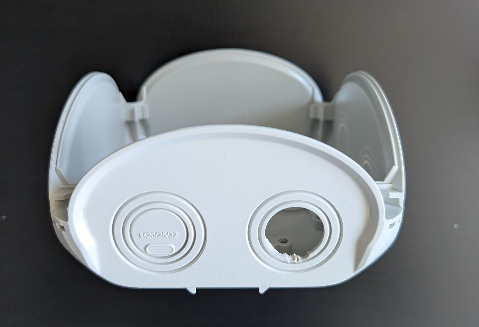
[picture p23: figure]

Drill 2 holes (green indicated) in the bottom, using 6mm drill bit. Also, bore out the holes indicated in red with 3.5mm.

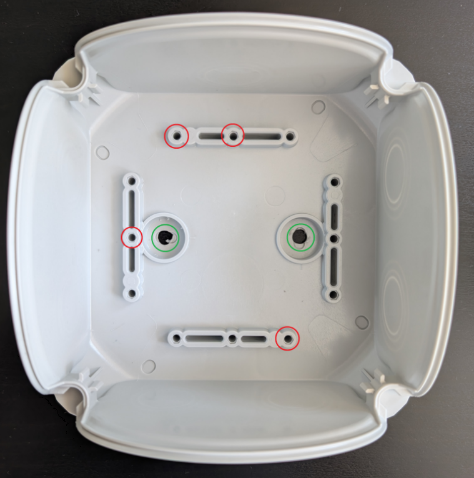
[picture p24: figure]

Screw the spacers in.

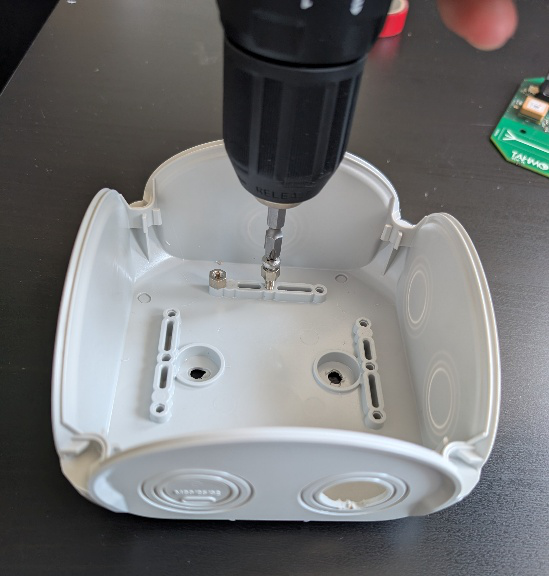
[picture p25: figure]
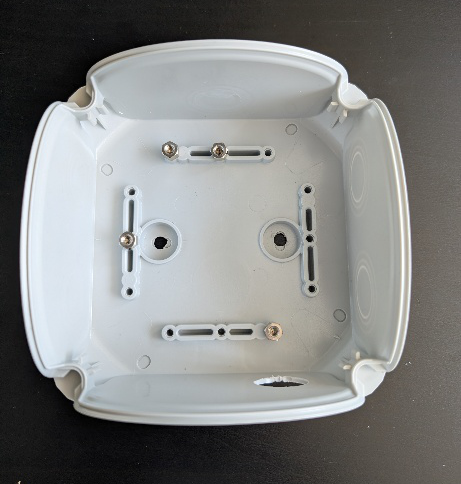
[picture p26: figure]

Mount the bracket using two bolts, washers and nuts.

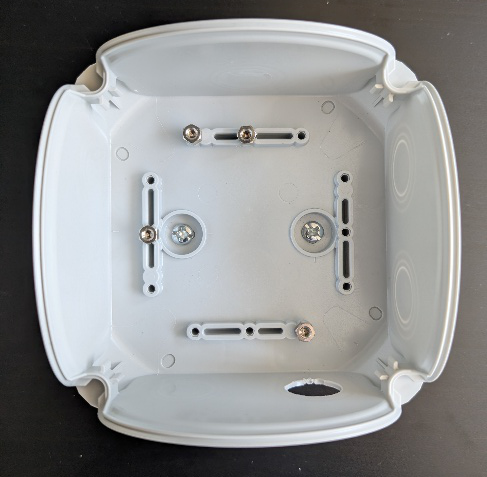
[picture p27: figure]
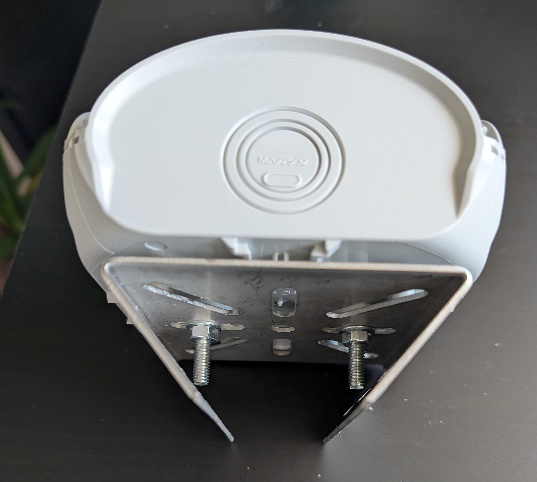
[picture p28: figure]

Insert the plugs to make the enclosure watertight.

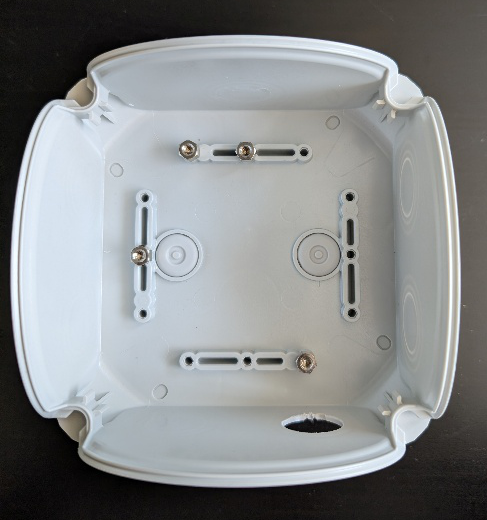
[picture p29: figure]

Screw the plastic spacers loosely on the PCB. Make sure you are still able to wiggle them.

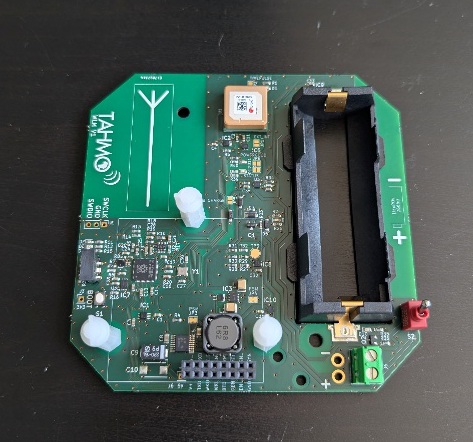
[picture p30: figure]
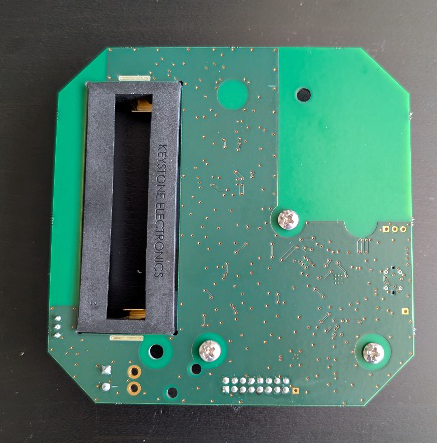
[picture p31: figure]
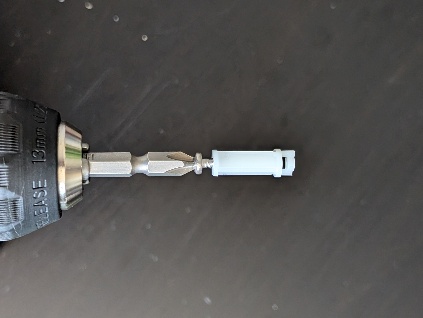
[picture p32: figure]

Mount the Rockblock and tighten the spacers.

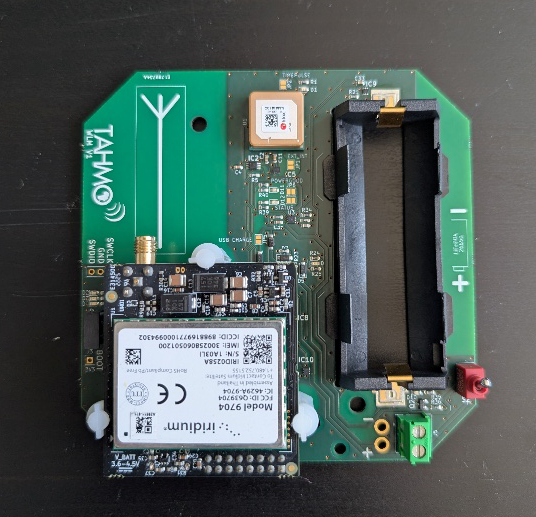
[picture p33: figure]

Solder the extension cable to the PCB. Alternative: Use the screwterminal.

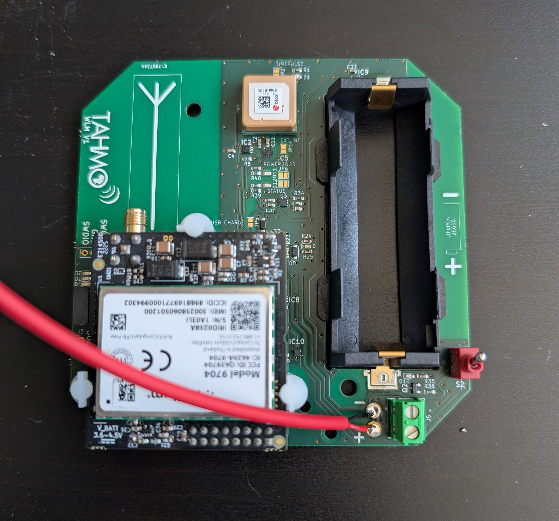
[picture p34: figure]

Mount the PCB in the enclosure with two bolts.

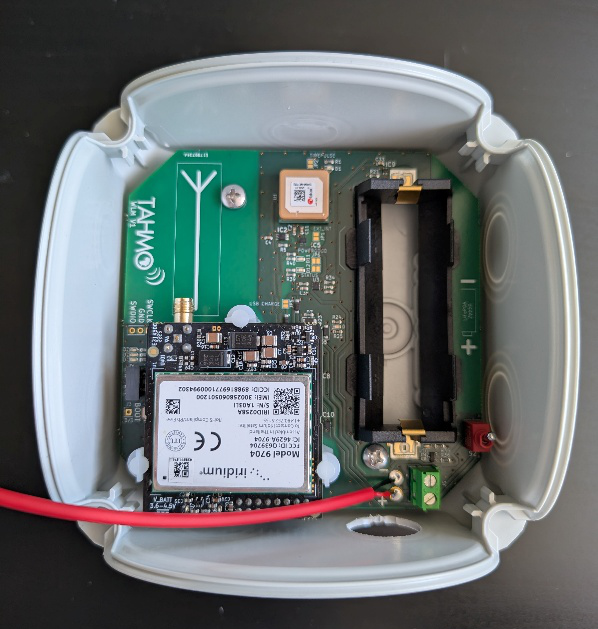
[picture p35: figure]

Add a bit of tape around the swivel to give it more grip into the enclosure. Pull the cable through and screw it into the enclosure.

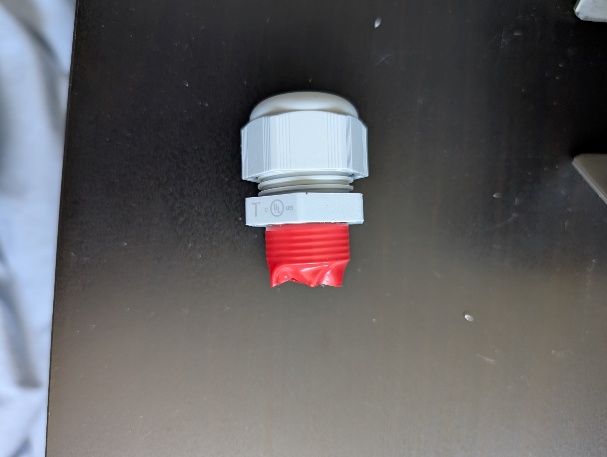
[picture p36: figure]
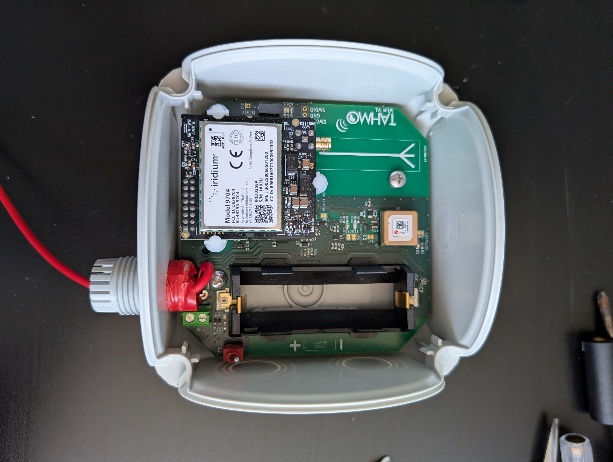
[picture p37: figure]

Add a bit of tape around the cable to increase its diameter. Tighten the swivel.

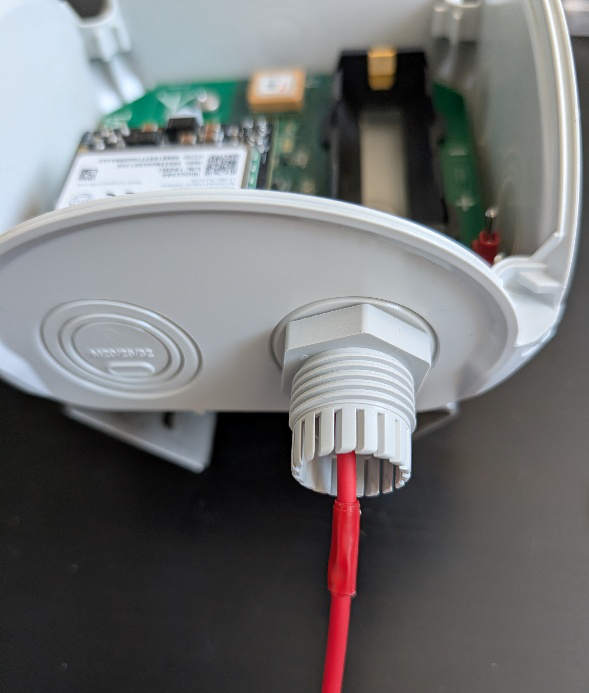
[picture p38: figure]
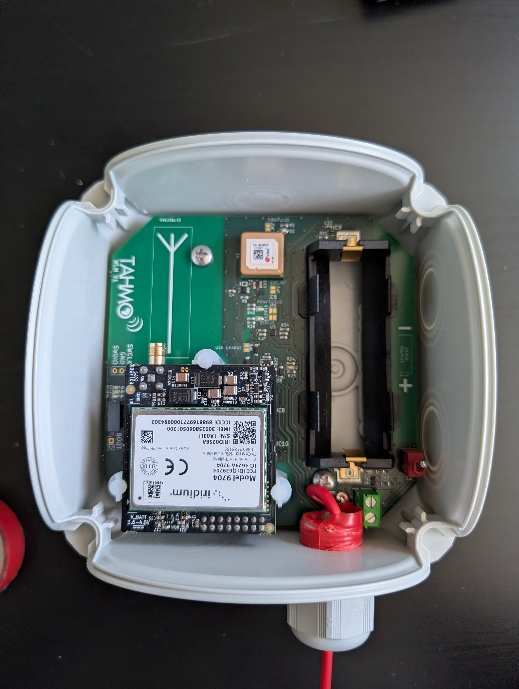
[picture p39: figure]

Screw the antenna on and mount the battery.

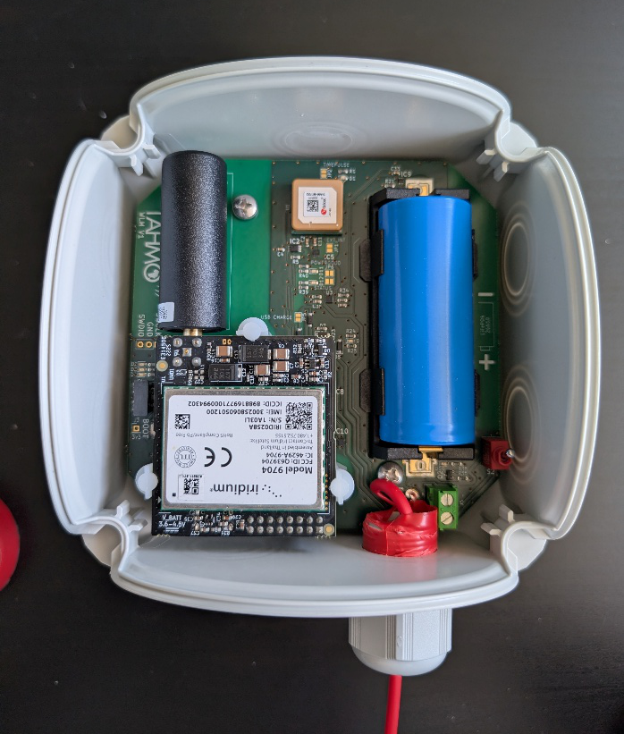
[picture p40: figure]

Close the lid.

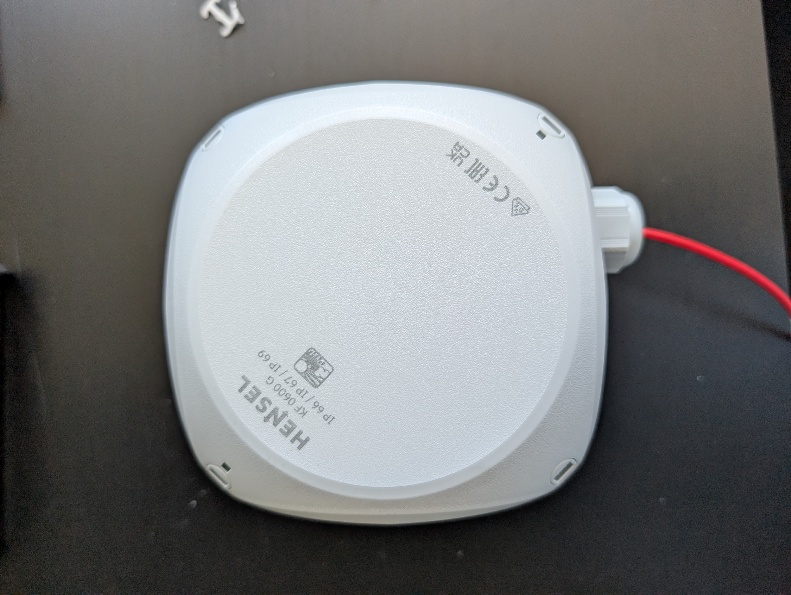
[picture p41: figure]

# Enable USB charging

If charging over USB is required, the pads marked ‘USB Charge’ should be connected with a drop of solder. This will draw 500mA from any

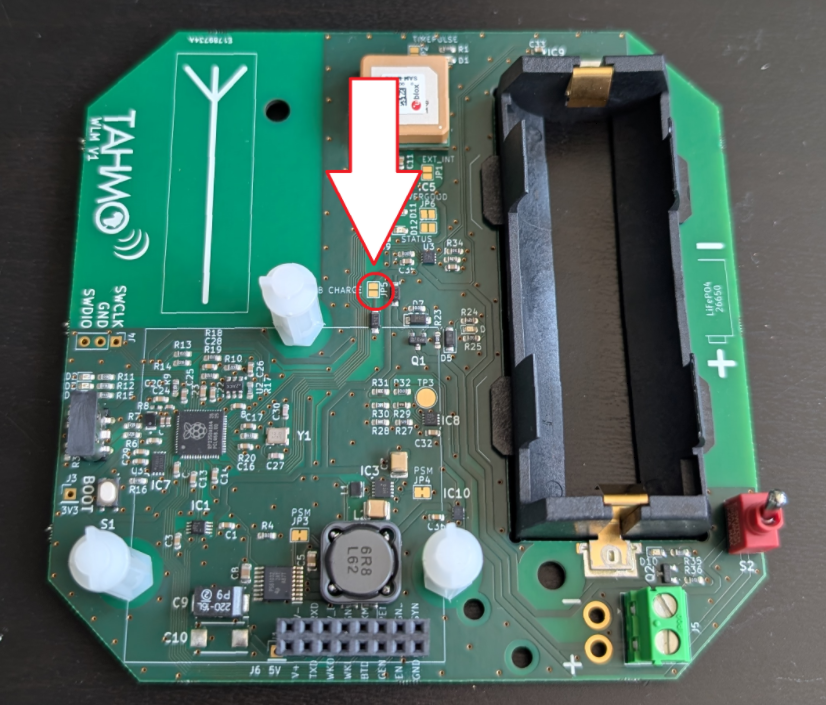
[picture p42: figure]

# Assembly Solar panel

Drill the two holes with 3.5mm.

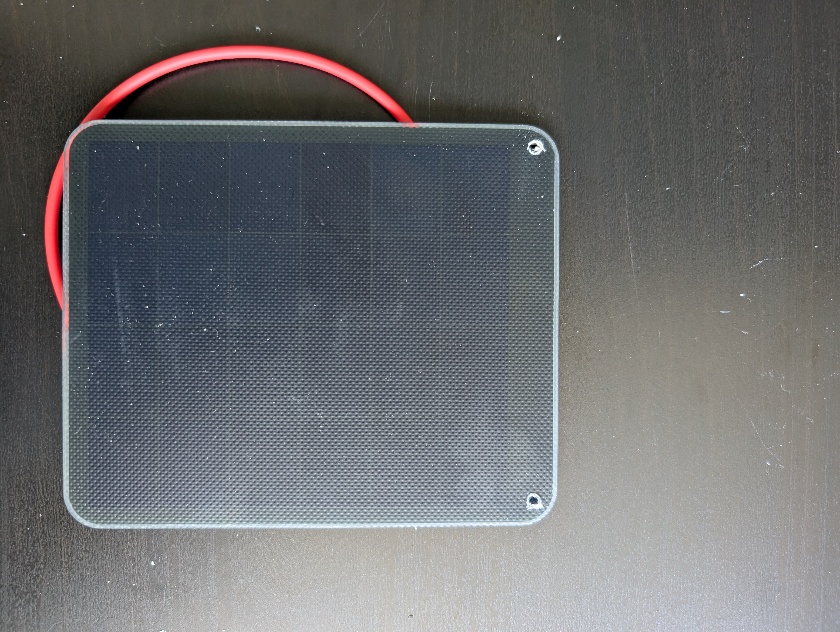
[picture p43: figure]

Attach bracket with bolts and nuts. (Orientation depends on how it will be mounted)

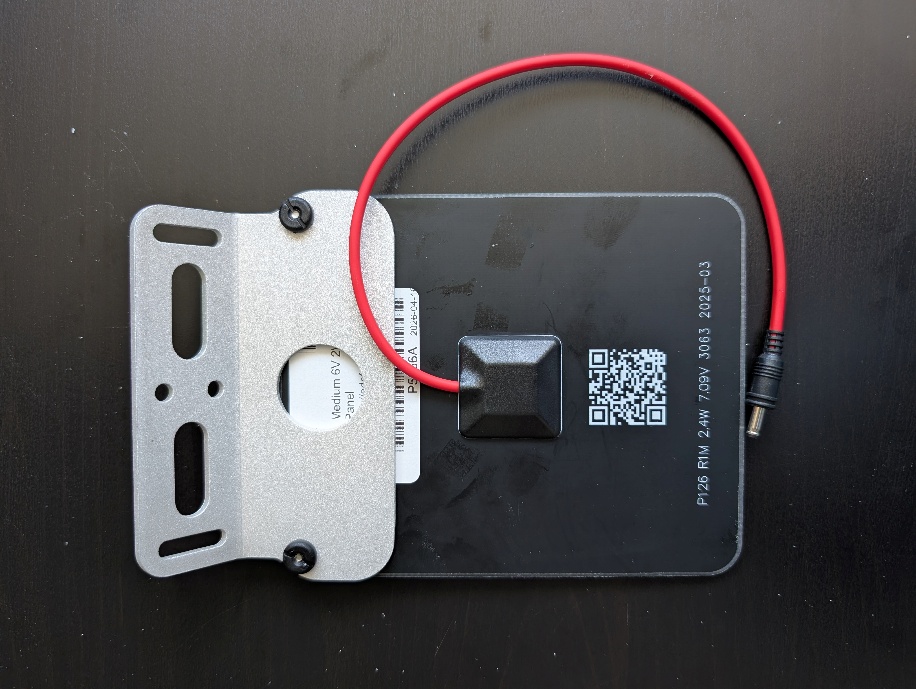
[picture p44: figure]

# Flashing firmware

To deploy the firmware on the device, follow the steps using https://stefanloen.github.io/tahmo/flash.html.

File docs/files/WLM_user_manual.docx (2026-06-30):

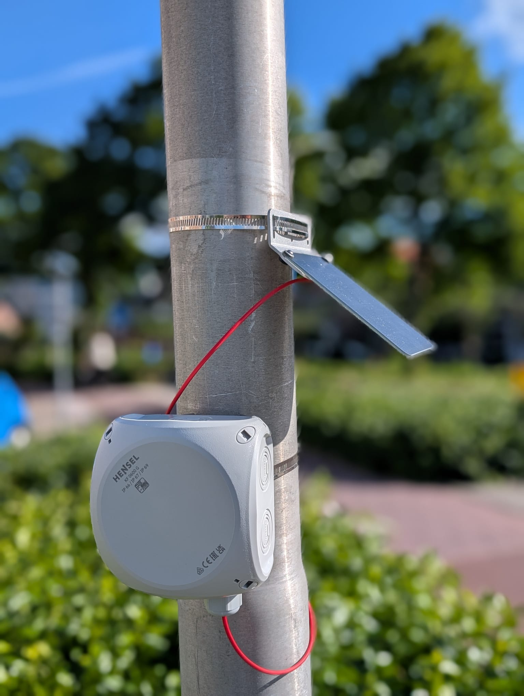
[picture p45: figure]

# WLM User Manual

## TAHMO Water Level Monitor system

This manual assumes that the device is already fully assembled including the battery and firmware. See assembly manual first if that is not the case.

# Feature overview

- GNSS: L1 Band, (GPS L1 C/A, QZSS L1 C/A L1S, GLONASS L1OF, BeiDou B1C, and Galileo E1B/C)
- Satellite communication: Iridium network
- Solar panel: 5V, device regulates 500mA maximum.
- Operating temperature: -20°C to 60°C (however, solar panel will not work <0°C)
- Operation time without solar panel: > 2 days.
- 17 hours raw data storage
- Configuration via USB
- Power toggle switch. When on green LED blinks every 5 seconds.
- Charging using USB (Note: If enabled on PCB, No indicator)
- Reverse polarity protection, Battery & Solar panel. LED indicator

# Installation

Place the system next to the water. Positioning is very important. The system needs to see reflections from the water. The spherical sector with an unobstructed view of the water should be as large as possible. The spherical sector is defined by the min-max azimuth and min-max elevation/altitude. A useful tool to see the reflection zones is https://gnss-reflections.org/rzones

Recommended elevation: 5° to 30°

Recommended azimuth: 90° minimal window. Bigger window is always better.

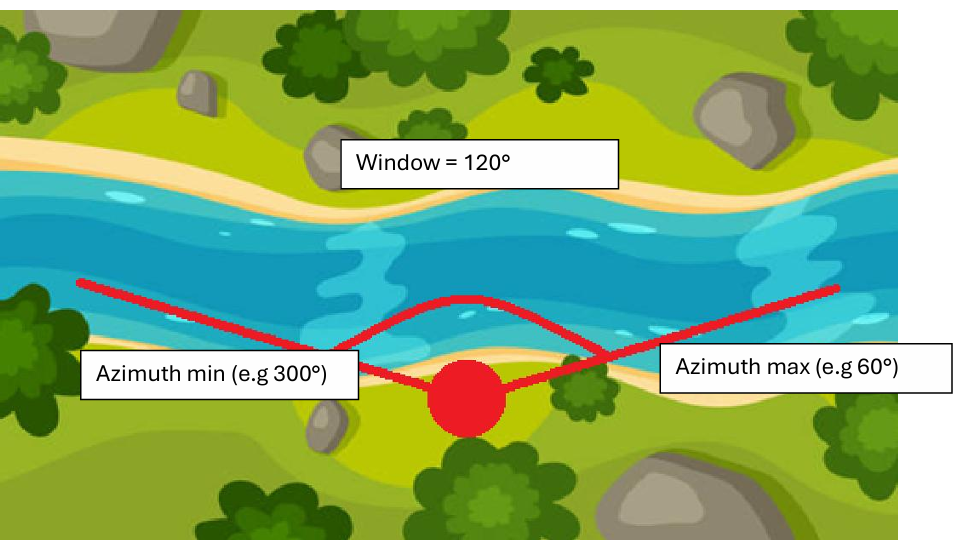
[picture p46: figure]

Figure 1: Example setup

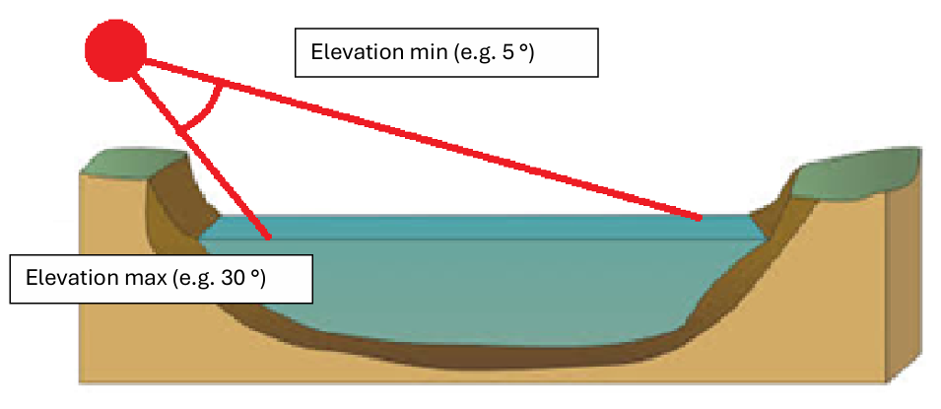
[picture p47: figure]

Figure 2: Example elevation setup

Other positioning requirements:

- The solar panel should be facing the sun.
- The cover of the system needs to roughly face the water. Orientation is okay as long as the azimuth window is on the cover side of the system.
- View to the sky should be as unobstructed as possible.
- Large reflective surfaces (e.g. a car) close to the system should be avoided

# Measurement details

There are a couple things that need to be configured:

Min and max azimuth window: This is where the water is located relative to the sensor. Finding the correct values can be done using a map or compass.

Min and max elevation window: This is how far the sensor should ‘look down’ towards the water.

Min and max relative height: This is the range of heights relative to the system for which measurements are expected. Setting this range larger than necessary might result in incorrect measurements.

Measurement midpoints and duration: Measuring is a matter of averaging over a long time. This defines when and how long measurements should be taken. Longer measurements are always better but consume more power. The measurements schedule is defined by a start-time, number of measurements per day, and the sector duration. For example, start-time=00:00:00, number=4, duration=120 minutes results in the following schedule:

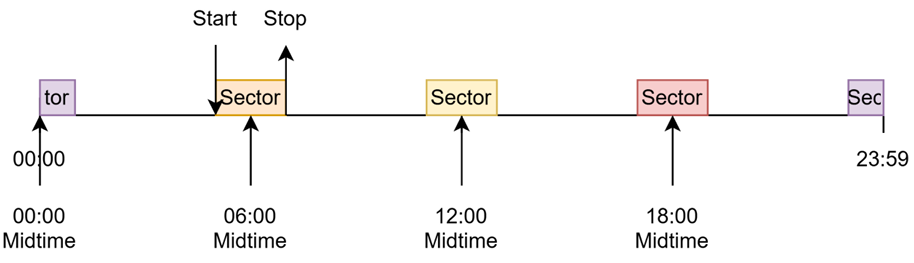
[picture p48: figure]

# Configuration

The device can be configured using any device capable of serial USB communication. The dedicated webpage to do this is https://stefanloen.github.io/tahmo/console.html, but other applications such as Serial USB Terminal (https://play.google.com/store/apps/details?id=de.kai_morich.serial_usb_terminal&pcampaignid=web_share) on Android or SST Simple Serial Terminal (https://apps.microsoft.com/detail/9p6m6gjsf3hn?hl=nl-NL&gl=NL&ocid=pdpshare) on Windows will work as well. This manual focuses on the webpage console.

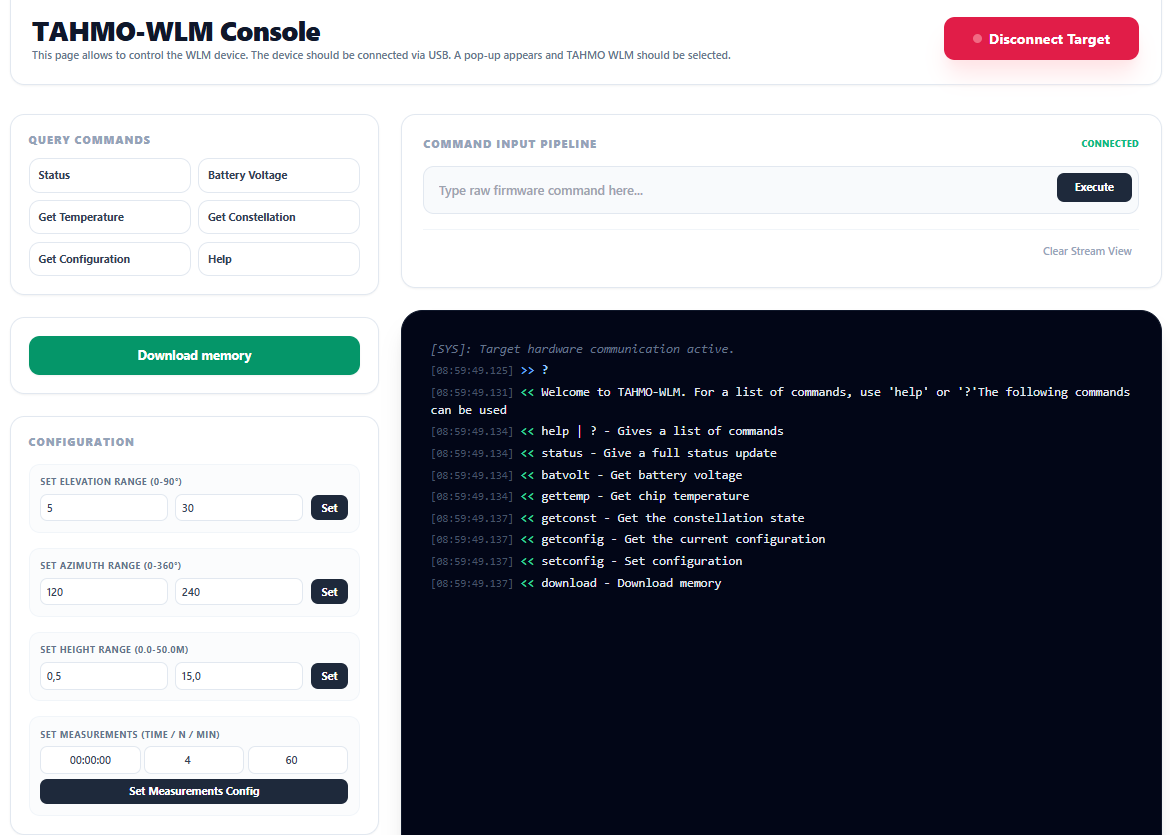
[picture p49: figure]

Figure 3: TAHMO-WLM Console is used to connect to the WLM device and set the configuration

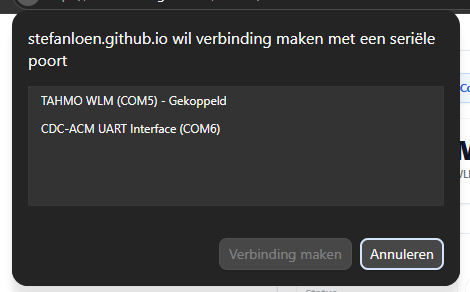
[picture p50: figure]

Figure 4: Popup where "TAHMO WLM" should be selected

The console is built on top of a plain text communication terminal, which is always visible in the serial viewer. The user can either send raw commands using the command input pipeline or use the Query Commands and Configuration shortcuts.

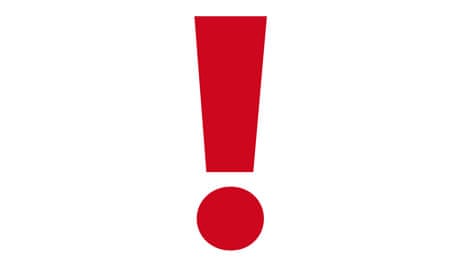
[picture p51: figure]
The joy of exclamation marks! | Written language | The Guardian

| There are certain edge cases where configuration is set incorrectly. After setting configurations, always check with getconfiguration.

| Communication sometimes fails, resulting in the message ‘aborted’. If this happens simply try again.

When a connection is established, the following message will appear:

Welcome to TAHMO-WLM. For a list of commands, use 'help' or '?'

Available commands:

help

Returns a list of available commands.

status

Returns the status of the device. It shows for example when the following measurement will be taken and which measurement is ready to be transmitted.

batvolt

Returns the battery voltage.

gettemp

Return the chip temperature

getconst

Returns the current constellation state, this might take a minute or two. This can be used to test the Rockblock. If constellation is not visible, installment location might be incorrect. Incorrect installment locations include under trees. However, even when constellation is not currently visible. It might be visible when satellites change positions. For the curious, satellite positions can be found on this website, https://iridiumwhere.com/.

getconfig

Returns the current configuration.

setconfig help

Returns a list of commands that can be combined with the setconfig command.

setconfig elevation <min> <max>

Sets the min and max elevation.

Example use: setconfig elevation 5 30

setconfig height

Sets the min and max relative height that is expected to be measured. It helps the system filtering out signals that fall outside of this range.

Example use: setconfig height 0.5 15

setconfig azimuth <min> <max>

Sets the min and max azimuth.

Example use: setconfig azimuth 120 240

setconfig measurements <midpoint> <n> <duration>

Sets the measurements schedule. It is defined by a midpoint (UTC+0), the number of measurements per day and the duration of a measurement in minutes.

Example use: setconfig measurements 00:00:00 4 120

download

This command triggers a full dump of memory over the serial USB connection. To store the raw data, one should use the ‘Download memory’ button on the webpage. This will call the ‘download’ command automatically and provides a ZIP file with data.

# Collecting measurements

All transmitted measurements are stored at https://data.cloudloop.com/. Data can be downloaded with the export function. The retrieved .CSV file can be viewed using https://stefanloen.github.io/tahmo/cloudloop.html. This plots the battery voltage, temperature and measured relative height over time. The decoded transmitted packets can also be found in table format.

Explanation F/NO/CH/ST Fractions:

This represents the states from the charge controller since the last transmission. It tells which fraction of the time it was in each state:
F: Fault

No: No input (Sun is not shining or solar panel is not connected

CH: Charging

Standby: Solar power available but not charging because battery is full or charging is blocked by temperature limits.

# Collecting raw data

To collect the raw data directly from the device, use https://stefanloen.github.io/tahmo/console.html. Connect and click ‘download’. This will extract the data and provide a ZIP file. The ZIP file contains 4 .CSV files. For the explanation of these files, one is advised to look at the firmware code.

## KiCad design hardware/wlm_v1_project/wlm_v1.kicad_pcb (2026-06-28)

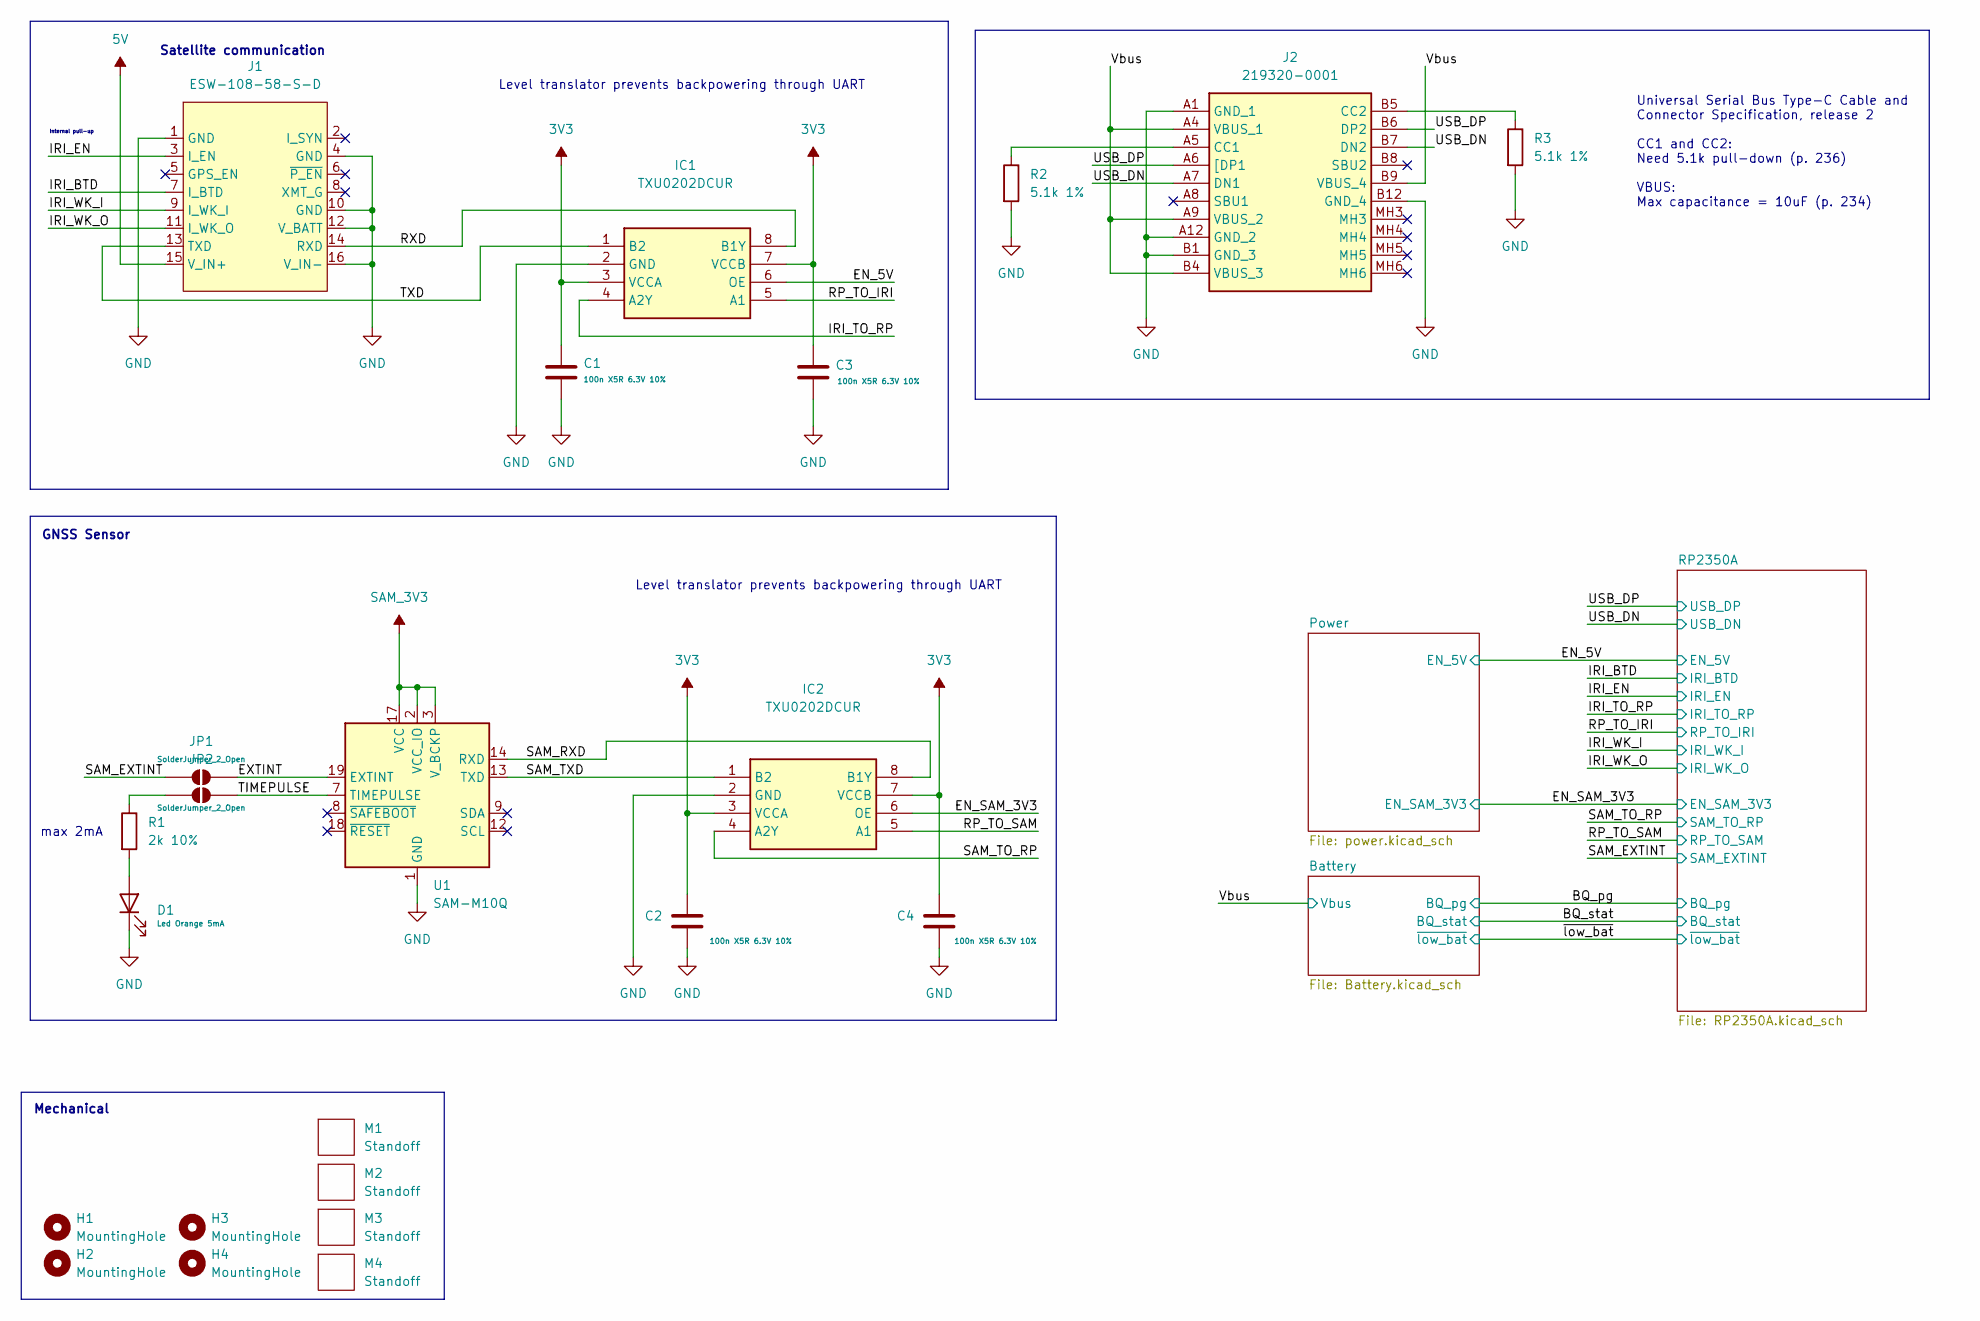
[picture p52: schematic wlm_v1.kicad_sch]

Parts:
C1, C2, C3, C4: 100n X5R 6.3V 10%; C_0603_1608Metric
D1: Led Orange 5mA; LED_0603_1608Metric
H1, H2, H3, H4: MountingHole; MountingHole_2.1mm
IC1, IC2: TXU0202DCUR; SOP50P310X90-8N; Mouser Part Number 595-TXU0202DCUR
J1: ESW-108-58-S-D; Rockblock_9704
J2: 219320-0001; 2193200001; Manufacturer_Part_Number 219320-0001; Mouser Part Number 538-219320-0001
JP1, JP2: SolderJumper_2_Open; SolderJumper-2_P1.3mm_Open_Pad1.0x1.5mm
M1, M2: Standoff; standoff_nohole
M3, M4: Standoff; standoff_hole
R1: 2k 10%; R_0603_1608Metric_Pad0.98x0.95mm_HandSolder
R2, R3: 5.1k 1%; R_0603_1608Metric_Pad0.98x0.95mm_HandSolder
U1: SAM-M10Q; ublox_SAM-M10Q

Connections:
3V3: C1.1, C2.1, C3.1, C4.1, IC1.3 (VCCA), IC1.7 (VCCB), IC2.3 (VCCA), IC2.7 (VCCB); also elsewhere on the board
5V: J1.15 (V_IN+); also elsewhere on the board
/EN_5V: IC1.6 (OE); also elsewhere on the board
/EN_SAM_3V3: IC2.6 (OE); also elsewhere on the board
/EXTINT: JP1.2 (B), U1.19 (EXTINT)
/IRI_BTD: J1.7 (I_BTD); also elsewhere on the board
/IRI_EN: J1.3 (I_EN); also elsewhere on the board
/IRI_TO_RP: IC1.4 (A2Y); also elsewhere on the board
/IRI_WK_I: J1.9 (I_WK_I); also elsewhere on the board
/IRI_WK_O: J1.11 (I_WK_O); also elsewhere on the board
/RP_TO_IRI: IC1.5 (A1); also elsewhere on the board
/RP_TO_SAM: IC2.5 (A1); also elsewhere on the board
/RXD: IC1.8 (B1Y), J1.14 (RXD)
/SAM_EXTINT: JP1.1 (A); also elsewhere on the board
/SAM_RXD: IC2.8 (B1Y), U1.14 (RXD)
/SAM_TO_RP: IC2.4 (A2Y); also elsewhere on the board
/SAM_TXD: IC2.1 (B2), U1.13 (TXD)
/TIMEPULSE: JP2.2 (B), U1.7 (TIMEPULSE)
/TXD: IC1.1 (B2), J1.13 (TXD)
/USB_DN: J2.A7 (DN1), J2.B7 (DN2); also elsewhere on the board
/USB_DP: J2.A6 ([DP1), J2.B6 (DP2); also elsewhere on the board
/Vbus: J2.A4 (VBUS_1), J2.A9 (VBUS_2), J2.B4 (VBUS_3), J2.B9 (VBUS_4); also elsewhere on the board
GND: C1.2, C2.2, C3.2, C4.2, D1.1 (K), IC1.2 (GND), IC2.2 (GND), J1.1 (GND), J1.4 (GND), J1.10 (GND), J1.12 (V_BATT), J1.16 (V_IN-), J2.A1 (GND_1), J2.A12 (GND_2), J2.B1 (GND_3), J2.B12 (GND_4), R2.2, R3.2, U1.1 (GND), U1.4 (GND), U1.5 (GND), U1.6 (GND), U1.10 (GND), U1.11 (GND), U1.15 (GND), U1.16 (GND), U1.20 (GND); also elsewhere on the board
unnamed: D1.2 (A), R1.2
unnamed: J2.A5 (CC1), R2.1
unnamed: J2.B5 (CC2), R3.1
unnamed: JP2.1 (A), R1.1
SAM_3V3: U1.2 (VCC_IO), U1.3 (V_BCKP), U1.17 (VCC); also elsewhere on the board

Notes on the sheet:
Internal pull-up
GNSS Sensor
Satellite communication
Mechanical
max 2mA
Universal Serial Bus Type-C Cable and Connector Specification, release 2 CC1 and CC2: Need 5.1k pull-down (p. 236) VBUS: Max capacitance = 10uF (p. 234)
Level translator prevents backpowering through UART
Level translator prevents backpowering through UART

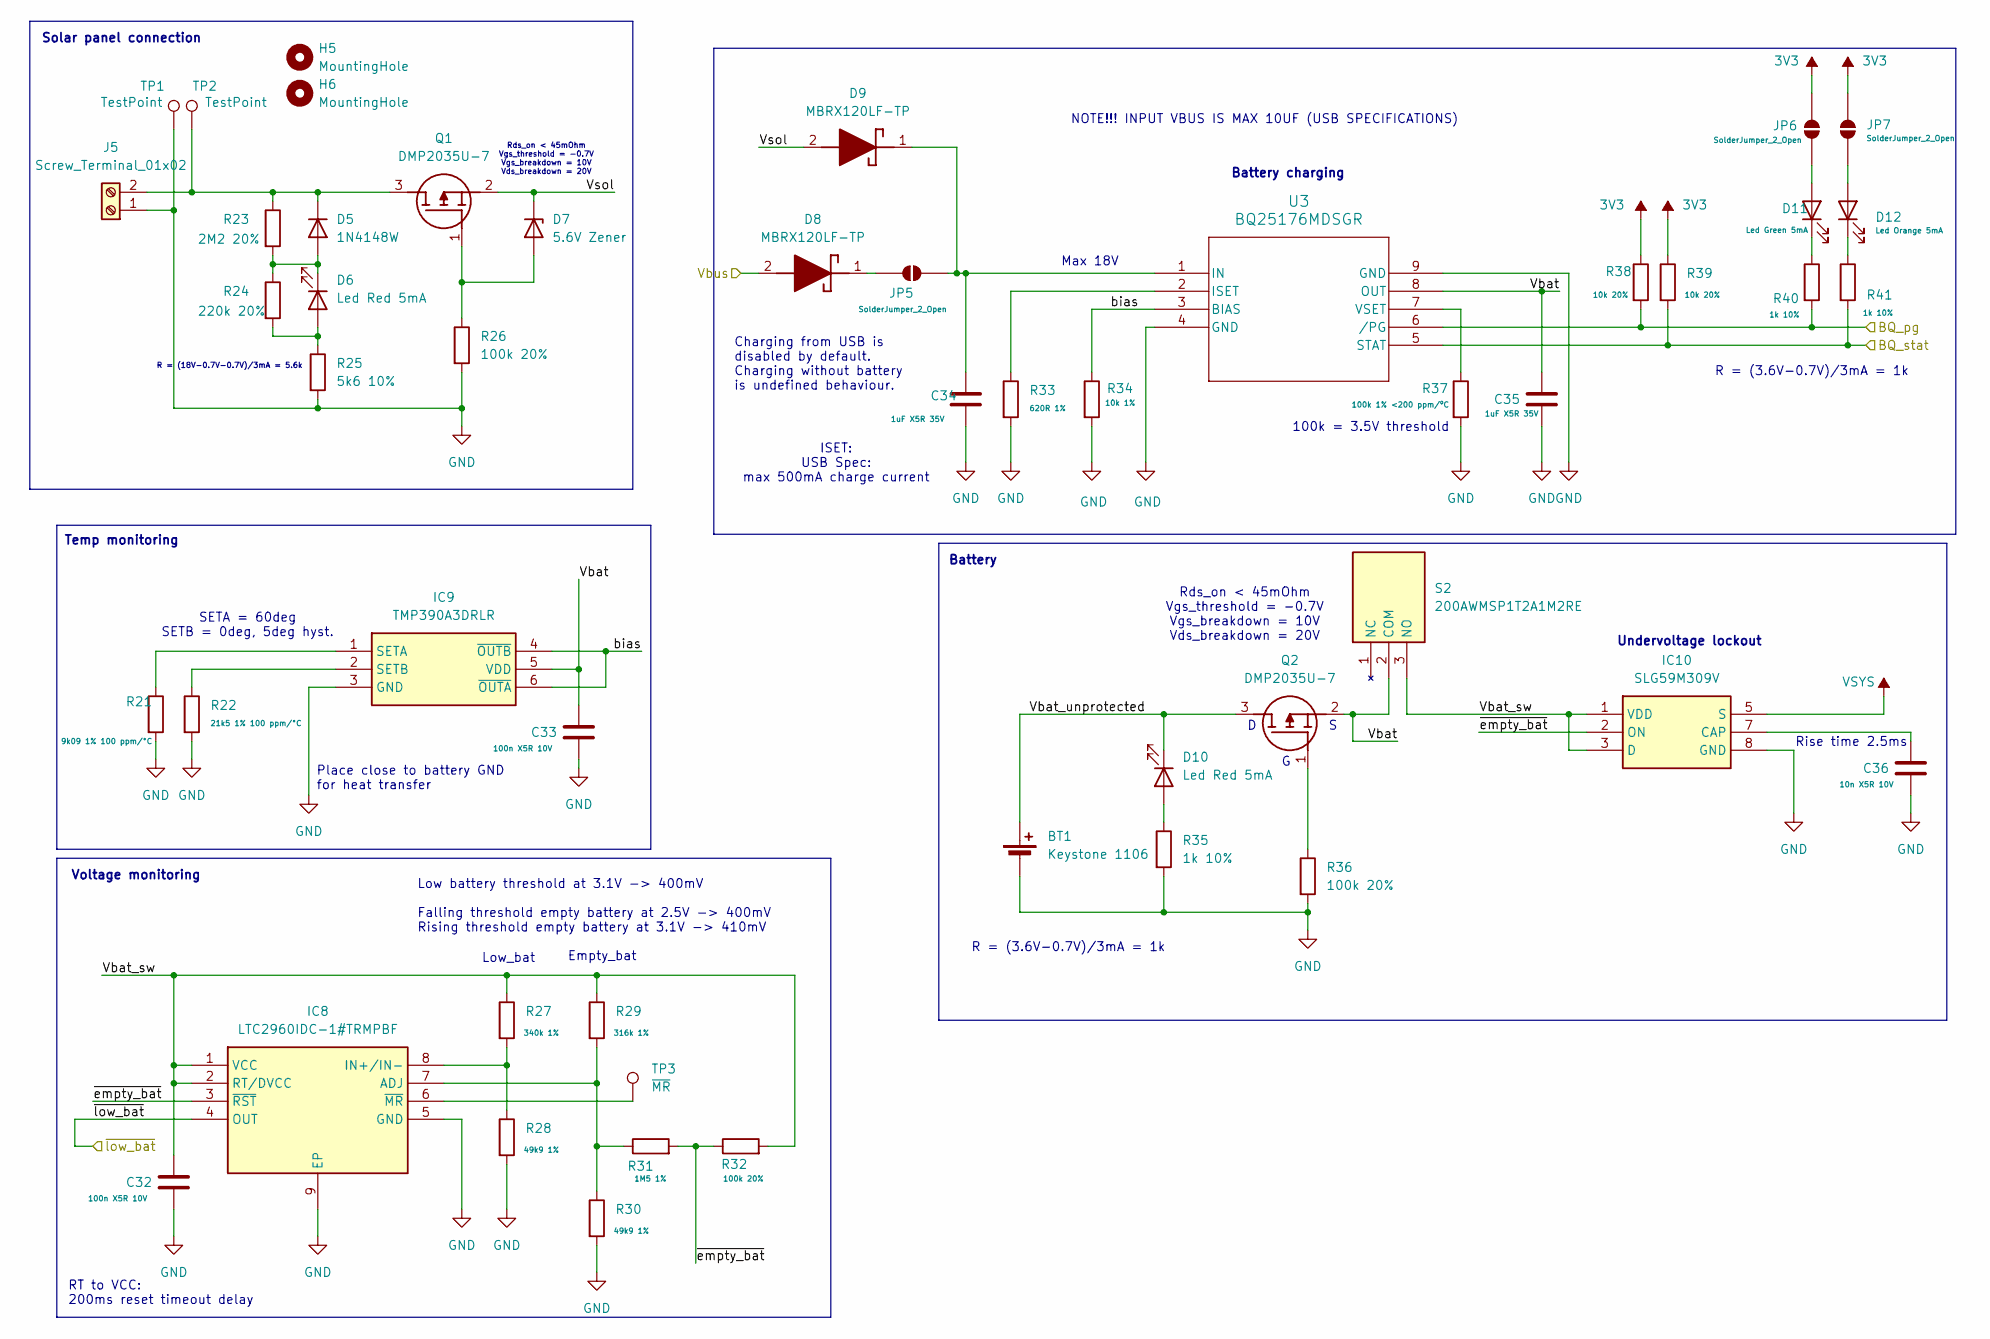
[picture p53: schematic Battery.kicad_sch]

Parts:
BT1: Keystone 1106; 26650_holder
C32, C33: 100n X5R 10V; C_0603_1608Metric
C34, C35: 1uF X5R 35V; C_0603_1608Metric
C36: 10n X5R 10V; C_0603_1608Metric
D5: 1N4148W; D_SOD-123
D6, D10: Led Red 5mA; LED_0603_1608Metric
D7: 5.6V Zener; D_SOD-123
D8, D9: MBRX120LF-TP; SOD3716X135N; Mouser Part Number 833-MBRX120LF-TP
D11: Led Green 5mA; LED_0603_1608Metric
D12: Led Orange 5mA; LED_0603_1608Metric
H5, H6: MountingHole; MountingHole_3.2mm_M3
IC8: LTC2960IDC-1#TRMPBF; SON45P200X200X80-9N-D; Mouser Part Number 584-C2960IDC-3TRMPBF
IC9: TMP390A3DRLR; SOTFL50P160X60-6N; Mouser Part Number 595-TMP390A3DRLR
IC10: SLG59M309V; Mouser Part Number 402-SLG59M309V
J5: Screw_Terminal_01x02; TerminalBlock_Phoenix_MKDS-1,5-2-5.08_1x02_P5.08mm_Horizont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
JP5, JP6, JP7: SolderJumper_2_Open; SolderJumper-2_P1.3mm_Open_Pad1.0x1.5mm
Q1, Q2: DMP2035U-7; DMP2035U7; Mouser Part Number 621-DMP2035U-7
R21: 9k09 1% 100 ppm/°C; R_0603_1608Metric_Pad0.98x0.95mm_HandSolder
R22: 21k5 1% 100 ppm/°C; R_0603_1608Metric_Pad0.98x0.95mm_HandSolder
R23: 2M2 20%; R_0603_1608Metric_Pad0.98x0.95mm_HandSolder
R24: 220k 20%; R_0603_1608Metric_Pad0.98x0.95mm_HandSolder
R25: 5k6 10%; R_0603_1608Metric_Pad0.98x0.95mm_HandSolder
R26, R32, R36: 100k 20%; R_0603_1608Metric_Pad0.98x0.95mm_HandSolder
R27: 340k 1%; R_0603_1608Metric_Pad0.98x0.95mm_HandSolder
R28, R30: 49k9 1%; R_0603_1608Metric_Pad0.98x0.95mm_HandSolder
R29: 316k 1%; R_0603_1608Metric_Pad0.98x0.95mm_HandSolder
R31: 1M5 1%; R_0603_1608Metric_Pad0.98x0.95mm_HandSolder
R33: 620R 1%; R_0603_1608Metric_Pad0.98x0.95mm_HandSolder
R34: 10k 1%; R_0603_1608Metric_Pad0.98x0.95mm_HandSolder
R35, R40, R41: 1k 10%; R_0603_1608Metric_Pad0.98x0.95mm_HandSolder
R37: 100k 1% <200 ppm/ºC; R_0603_1608Metric_Pad0.98x0.95mm_HandSolder
R38, R39: 10k 20%; R_0603_1608Metric_Pad0.98x0.95mm_HandSolder
S2: 200AWMSP1T2A1M2RE; Mouser Part Number 612-200A-A2162
TP1, TP2: TestPoint; TestPoint_THTPad_D2.0mm_Drill1.0mm
TP3: ~{MR}; TestPoint_Pad_D3.0mm
U3: BQ25176MDSGR; WSON_MDSGR_TEX

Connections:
3V3: JP6.2 (B), JP7.2 (B), R38.1, R39.1; also elsewhere on the board
/BQ_pg: R38.2, R40.2, U3.6 (/PG); also elsewhere on the board
/BQ_stat: R39.2, R41.2, U3.5 (STAT); also elsewhere on the board
/Battery/Vbat: C33.1, C35.1, IC9.5 (VDD), Q2.2 (S), S2.2 (COM), U3.8 (OUT)
/Battery/Vbat_sw: C32.1, IC8.1 (VCC), IC8.2 (RT/DVCC), IC10.1 (VDD), IC10.3 (D), R27.1, R29.1, R32.2, S2.3 (NO)
/Battery/Vbat_unprotected: BT1.1 (+), D10.1 (K), Q2.3 (D)
/Battery/Vsol: D7.1 (K), D9.2 (A), Q1.2 (S)
/Battery/bias: IC9.4 (~OUTB), IC9.6 (~OUTA), R34.1, U3.3 (BIAS)
/Battery/~empty_bat: IC8.3 (~RST), IC10.2 (ON), R31.2, R32.1
/Vbus: D8.2 (A); also elsewhere on the board
/~low_bat: IC8.4 (OUT); also elsewhere on the board
GND: BT1.2 (-), C32.2, C33.2, C34.2, C35.2, C36.2, IC8.5 (GND), IC8.9 (EP), IC9.3 (GND), IC10.8 (GND), J5.1, R21.2, R22.2, R25.2, R26.2, R28.2, R30.2, R33.2, R34.2, R35.2, R36.2, R37.2, TP1.1 (1_1), U3.4 (GND), U3.9 (GND); also elsewhere on the board
unnamed: D5.2 (A), D6.1 (K), R23.2, R24.1
unnamed: D5.1 (K), J5.2, Q1.3 (D), R23.1, TP2.1 (1_1)
unnamed: D6.2 (A), R24.2, R25.1
unnamed: D7.2 (A), Q1.1 (G), R26.1
unnamed: D8.1 (K), JP5.2 (B)
unnamed: C34.1, D9.1 (K), JP5.1 (A), U3.1 (IN)
unnamed: D10.2 (A), R35.1
unnamed: D11.2 (A), JP6.1 (A)
unnamed: D11.1 (K), R40.1
unnamed: D12.2 (A), JP7.1 (A)
unnamed: D12.1 (K), R41.1
unnamed: IC8.7 (ADJ), R29.2, R30.1, R31.1
unnamed: IC8.8 (IN+/IN-), R27.2, R28.1
unnamed: IC8.6 (~MR), TP3.1 (1_1)
unnamed: IC9.1 (SETA), R21.1
unnamed: IC9.2 (SETB), R22.1
unnamed: C36.1, IC10.7 (CAP)
unnamed: Q2.1 (G), R36.1
unnamed: R33.1, U3.2 (ISET)
unnamed: R37.1, U3.7 (VSET)
VSYS: IC10.5 (S); also elsewhere on the board

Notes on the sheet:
Voltage monitoring
Battery
Empty_bat
SETA = 60deg SETB = 0deg, 5deg hyst.
Place close to battery GND for heat transfer
ISET: USB Spec: max 500mA charge current
Max 18V
Rds_on < 45mOhm Vgs_threshold = -0.7V Vgs_breakdown = 10V Vds_breakdown = 20V
RT to VCC: 200ms reset timeout delay
R = (18V-0.7V-0.7V)/3mA = 5.6k
R = (3.6V-0.7V)/3mA = 1k
Temp monitoring
100k = 3.5V threshold
Solar panel connection
Low battery threshold at 3.1V -> 400mV Falling threshold empty battery at 2.5V -> 400mV Rising threshold empty battery at 3.1V -> 410mV
Charging from USB is disabled by default. Charging without battery is undefined behaviour.
Battery charging
Low_bat
Undervoltage lockout
Rise time 2.5ms
NOTE!!! INPUT VBUS IS MAX 10UF (USB SPECIFICATIONS)

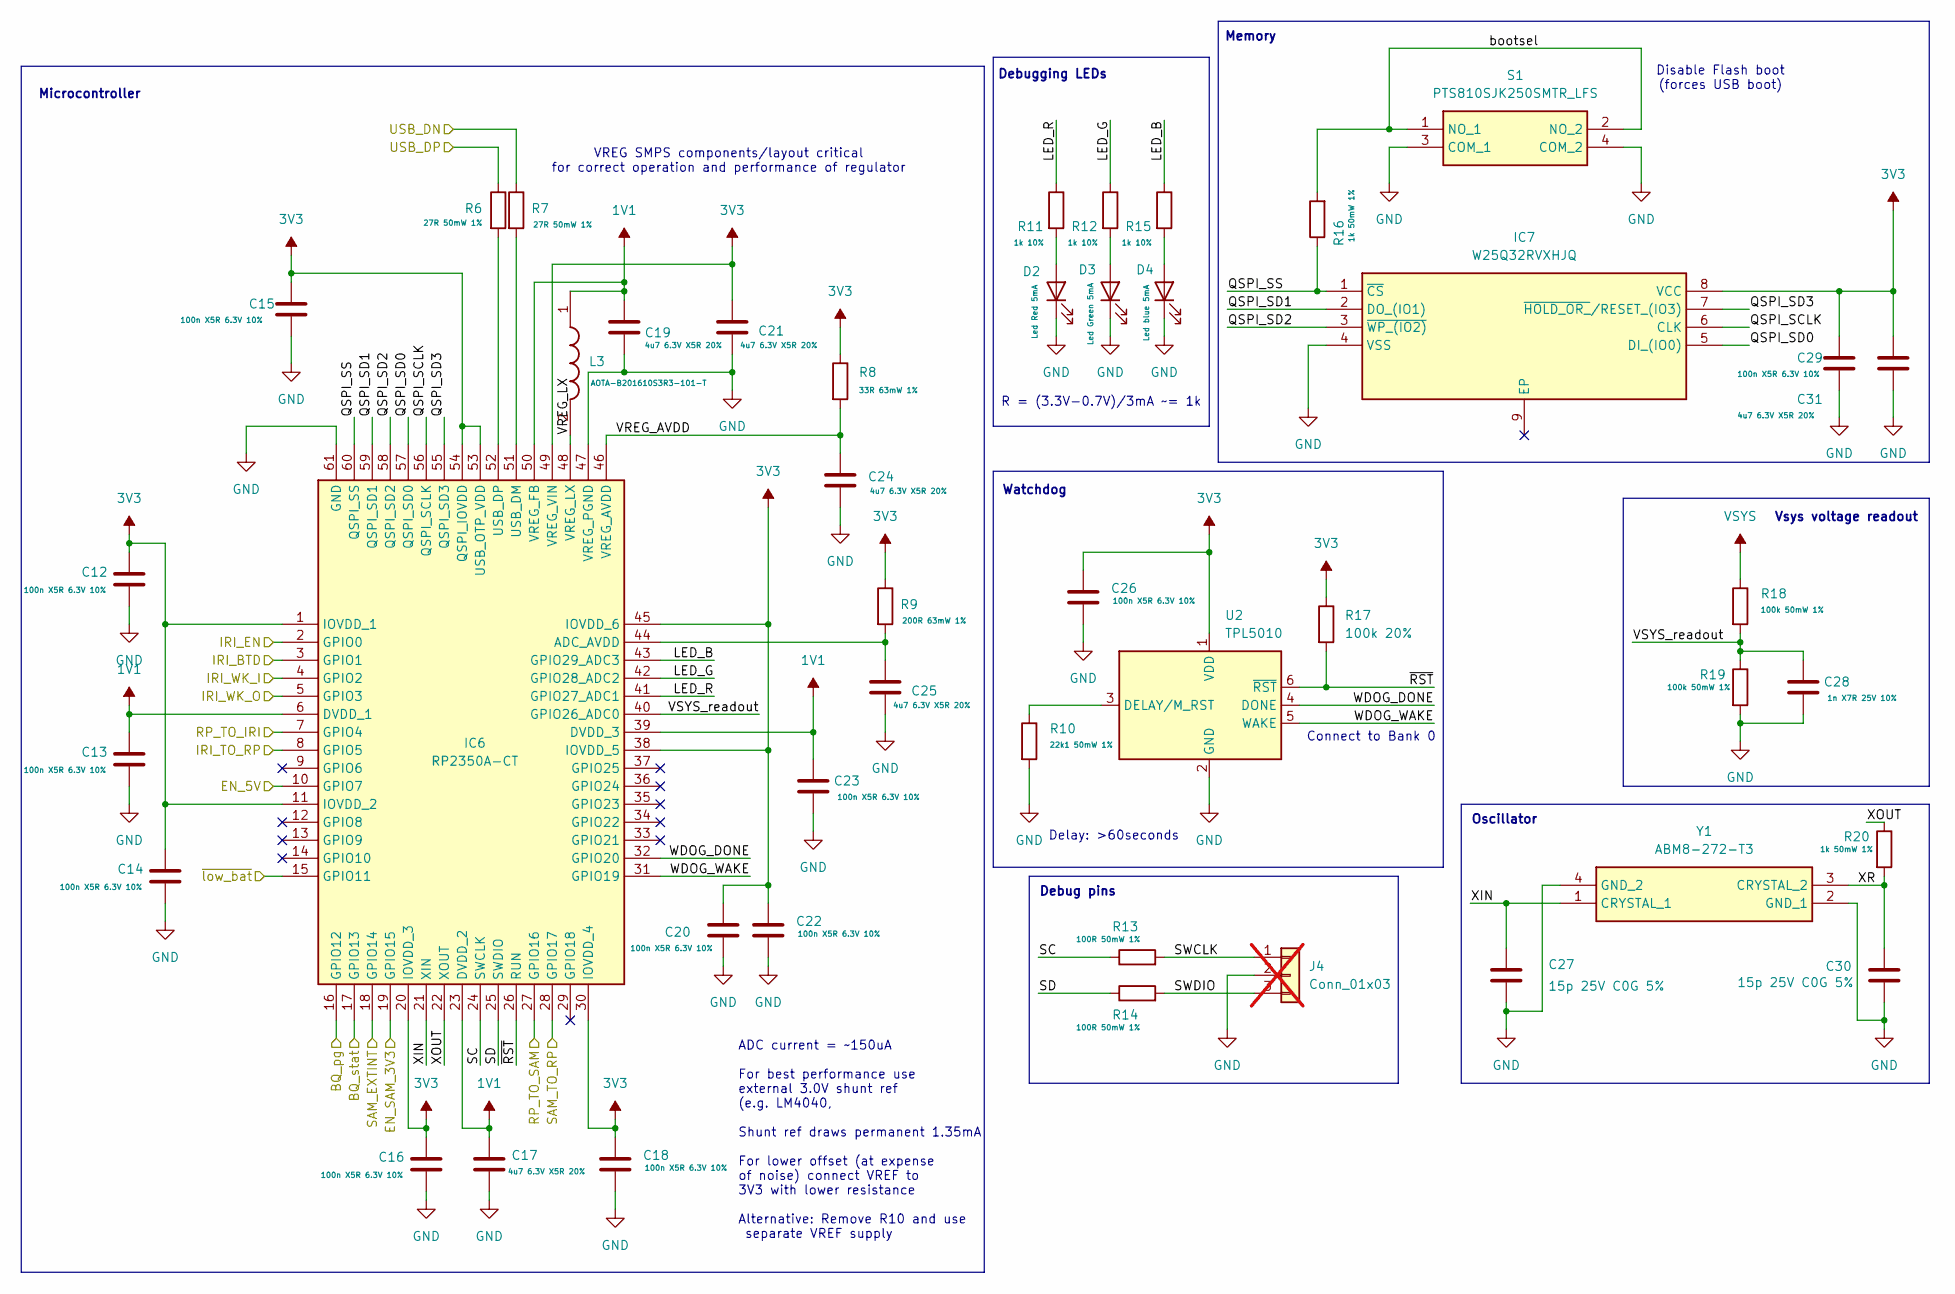
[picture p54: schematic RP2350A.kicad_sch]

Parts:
C12, C13, C14, C15, C16, C18, C20, C22, C23, C26, C29: 100n X5R 6.3V 10%; C_0603_1608Metric
C17, C25, C31: 4u7 6.3V X5R 20%; C_0603_1608Metric
C19, C21, C24: 4u7 6.3V X5R 20%; C_0402_1005Metric
C27, C30: 15p 25V C0G 5%; C_0603_1608Metric
C28: 1n X7R 25V 10%; C_0603_1608Metric
D2: Led Red 5mA; LED_0603_1608Metric
D3: Led Green 5mA; LED_0603_1608Metric
D4: Led blue 5mA; LED_0603_1608Metric
IC6: RP2350A-CT; QFN40P700X700X90-61N-D; Manufacturer_Part_Number RP2350A-CT
IC7: W25Q32RVXHJQ; SON50P300X200X40-9N; Manufacturer_Part_Number W25Q32RVXHJQ
J4: Conn_01x03; PinHeader_1x03_P2.54mm_Vertical; not fitted
L3: AOTA-B201610S3R3-101-T; AOTAB201610S3R3101T; Mouser Part Number 815-AB201610S3R3101T
R6, R7: 27R 50mW 1%; R_0603_1608Metric_Pad0.98x0.95mm_HandSolder
R8: 33R 63mW 1%; R_0402_1005Metric_Pad0.72x0.64mm_HandSolder
R9: 200R 63mW 1%; R_0603_1608Metric_Pad0.98x0.95mm_HandSolder
R10: 22k1 50mW 1%; R_0603_1608Metric_Pad0.98x0.95mm_HandSolder
R11, R12, R15: 1k 10%; R_0603_1608Metric_Pad0.98x0.95mm_HandSolder
R13, R14: 100R 50mW 1%; R_0603_1608Metric_Pad0.98x0.95mm_HandSolder
R16, R20: 1k 50mW 1%; R_0603_1608Metric_Pad0.98x0.95mm_HandSolder
R17: 100k 20%; R_0603_1608Metric_Pad0.98x0.95mm_HandSolder
R18, R19: 100k 50mW 1%; R_0603_1608Metric_Pad0.98x0.95mm_HandSolder
S1: PTS810SJK250SMTR_LFS; PTS810SJK250SMTRLFS; Mouser Part Number 611-PTS810SJK250SMTR
U2: TPL5010; SOT-23-6
Y1: ABM8-272-T3; ABM8272T3; Mouser Part Number 815-ABM8-272-T3

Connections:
1V1: C13.1, C17.1, C19.1, C23.1, IC6.6 (DVDD_1), IC6.23 (DVDD_2), IC6.39 (DVDD_3), IC6.50 (VREG_FB), L3.1
3V3: C12.1, C14.1, C15.1, C16.1, C18.1, C20.1, C21.1, C22.1, C26.1, C29.1, C31.1, IC6.1 (IOVDD_1), IC6.11 (IOVDD_2), IC6.20 (IOVDD_3), IC6.30 (IOVDD_4), IC6.38 (IOVDD_5), IC6.45 (IOVDD_6), IC6.49 (VREG_VIN), IC6.53 (USB_OTP_VDD), IC6.54 (QSPI_IOVDD), IC7.8 (VCC), R8.1, R9.1, R17.1, U2.1 (VDD); also elsewhere on the board
/BQ_pg: IC6.16 (GPIO12); also elsewhere on the board
/BQ_stat: IC6.17 (GPIO13); also elsewhere on the board
/EN_5V: IC6.10 (GPIO7); also elsewhere on the board
/EN_SAM_3V3: IC6.19 (GPIO15); also elsewhere on the board
/IRI_BTD: IC6.3 (GPIO1); also elsewhere on the board
/IRI_EN: IC6.2 (GPIO0); also elsewhere on the board
/IRI_TO_RP: IC6.8 (GPIO5); also elsewhere on the board
/IRI_WK_I: IC6.4 (GPIO2); also elsewhere on the board
/IRI_WK_O: IC6.5 (GPIO3); also elsewhere on the board
/RP2350A/LED_B: IC6.43 (GPIO29_ADC3), R15.1
/RP2350A/LED_G: IC6.42 (GPIO28_ADC2), R12.1
/RP2350A/LED_R: IC6.41 (GPIO27_ADC1), R11.1
/RP2350A/QSPI_SCLK: IC6.56 (QSPI_SCLK), IC7.6 (CLK)
/RP2350A/QSPI_SD0: IC6.57 (QSPI_SD0), IC7.5 (DI_(IO0))
/RP2350A/QSPI_SD1: IC6.59 (QSPI_SD1), IC7.2 (DO_(IO1))
/RP2350A/QSPI_SD2: IC6.58 (QSPI_SD2), IC7.3 (~WP_(IO2))
/RP2350A/QSPI_SD3: IC6.55 (QSPI_SD3), IC7.7 (~HOLD_OR_/RESET_(IO3))
/RP2350A/QSPI_SS: IC6.60 (QSPI_SS), IC7.1 (~CS), R16.1
/RP2350A/SC: IC6.24 (SWCLK), R13.1
/RP2350A/SD: IC6.25 (SWDIO), R14.1
/RP2350A/SWCLK: J4.1, R13.2
/RP2350A/SWDIO: J4.3, R14.2
/RP2350A/VREG_AVDD: C24.1, IC6.46 (VREG_AVDD), R8.2
/RP2350A/VREG_LX: IC6.48 (VREG_LX), L3.2
/RP2350A/VSYS_readout: C28.1, IC6.40 (GPIO26_ADC0), R18.2, R19.1
/RP2350A/WDOG_DONE: IC6.32 (GPIO20), U2.4 (DONE)
/RP2350A/WDOG_WAKE: IC6.31 (GPIO19), U2.5 (WAKE)
/RP2350A/XIN: C27.1, IC6.21 (XIN), Y1.1 (CRYSTAL_1)
/RP2350A/XOUT: IC6.22 (XOUT), R20.1
/RP2350A/XR: C30.1, R20.2, Y1.3 (CRYSTAL_2)
/RP2350A/bootsel: R16.2, S1.1 (NO_1), S1.2 (NO_2)
/RP2350A/~RST: IC6.26 (RUN), R17.2, U2.6 (~RST)
/RP_TO_IRI: IC6.7 (GPIO4); also elsewhere on the board
/RP_TO_SAM: IC6.27 (GPIO16); also elsewhere on the board
/SAM_EXTINT: IC6.18 (GPIO14); also elsewhere on the board
/SAM_TO_RP: IC6.28 (GPIO17); also elsewhere on the board
/USB_DN: R7.1; also elsewhere on the board
/USB_DP: R6.1; also elsewhere on the board
/~low_bat: IC6.15 (GPIO11); also elsewhere on the board
GND: C12.2, C13.2, C14.2, C15.2, C16.2, C17.2, C18.2, C19.2, C20.2, C21.2, C22.2, C23.2, C24.2, C25.2, C26.2, C27.2, C28.2, C29.2, C30.2, C31.2, D2.1 (K), D3.1 (K), D4.1 (K), IC6.47 (VREG_PGND), IC6.61 (GND), IC7.4 (VSS), J4.2, R10.2, R19.2, S1.3 (COM_1), S1.4 (COM_2), U2.2 (GND), Y1.2 (GND_1), Y1.4 (GND_2); also elsewhere on the board
unnamed: D2.2 (A), R11.2
unnamed: D3.2 (A), R12.2
unnamed: D4.2 (A), R15.2
unnamed: C25.1, IC6.44 (ADC_AVDD), R9.2
unnamed: IC6.51 (USB_DM), R7.2
unnamed: IC6.52 (USB_DP), R6.2
unnamed: R10.1, U2.3 (DELAY/M_RST)
VSYS: R18.1; also elsewhere on the board

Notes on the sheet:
Delay: >60seconds
Watchdog
Disable Flash boot (forces USB boot)
Vsys voltage readout
Debug pins
Debugging LEDs
VREG SMPS components/layout critical for correct operation and performance of regulator
Microcontroller
Memory
Oscillator
ADC current = ~150uA For best performance use external 3.0V shunt ref (e.g. LM4040, Shunt ref draws permanent 1.35mA For lower offset (at expense of noise) connect VREF to 3V3 with lower resistance Alternative: Remove R10 and use separate VREF supply
Connect to Bank 0
R = (3.3V-0.7V)/3mA ~= 1k

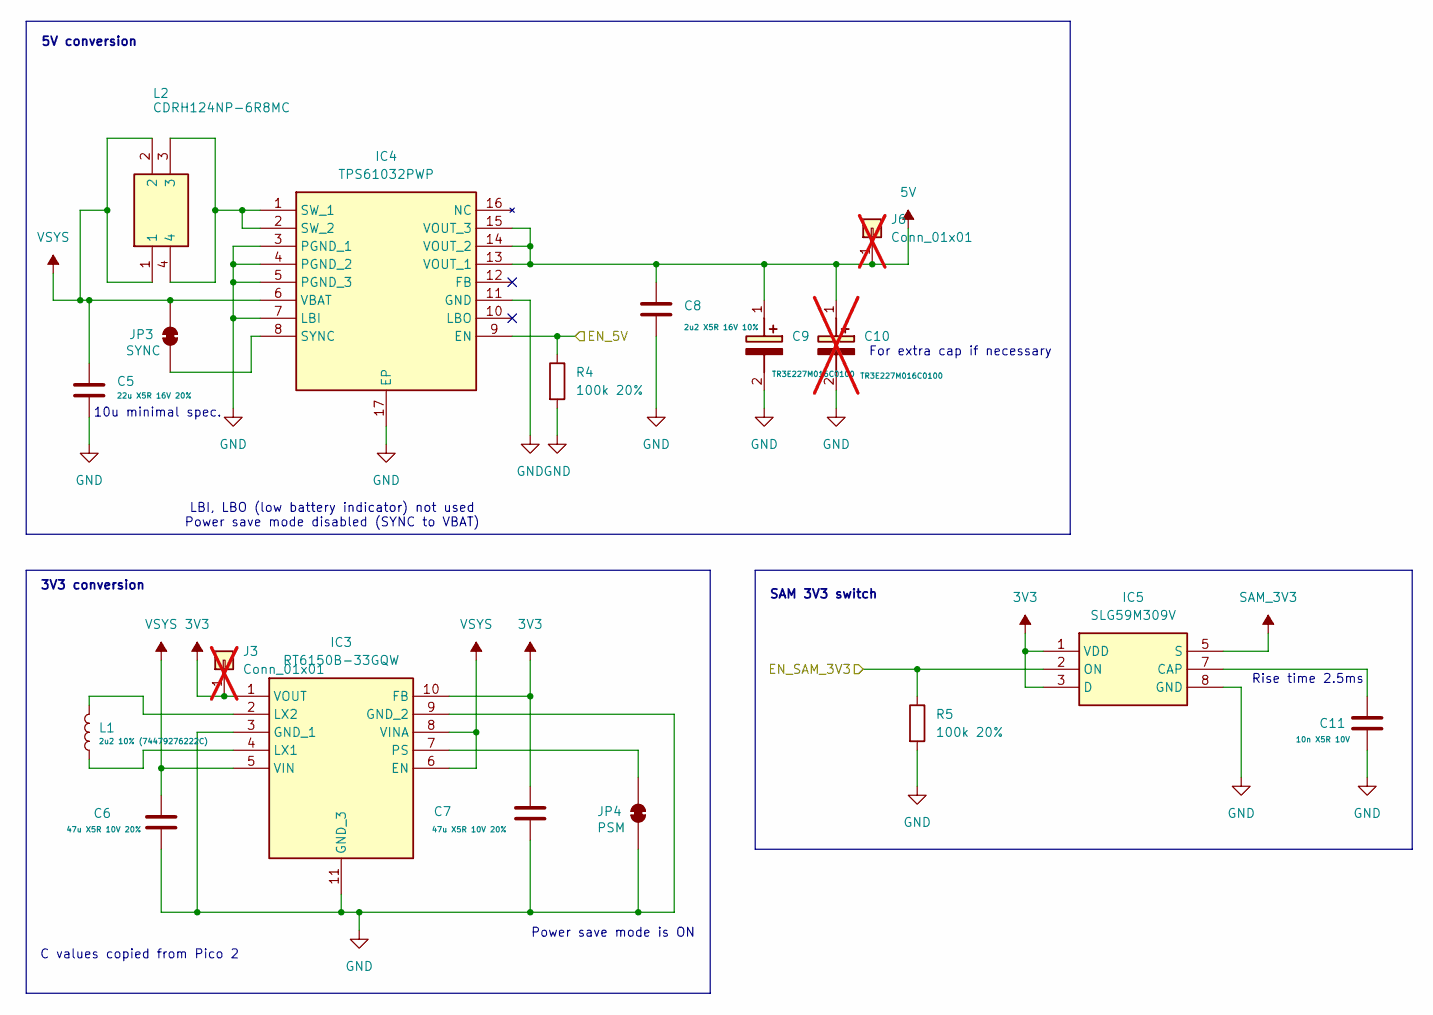
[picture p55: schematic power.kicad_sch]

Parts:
C5: 22u X5R 16V 20%; C_0805_2012Metric
C6, C7: 47u X5R 10V 20%; C_1210_3225Metric
C8: 2u2 X5R 16V 10%; C_0805_2012Metric
C9: TR3E227M016C0100; CAPPM7343X430N; Mouser Part Number 74-TR3E227M016C0100
C10: TR3E227M016C0100; CAPPM7343X430N; Mouser Part Number 74-TR3E227M016C0100; not fitted
C11: 10n X5R 10V; C_0603_1608Metric
IC3: RT6150B-33GQW; SON50P250X250X80-11N-D; Mouser Part Number 835-RT6150B-33GQW
IC4: TPS61032PWP; SOP65P640X120-17N; Mouser Part Number 595-TPS61032PWPR
IC5: SLG59M309V; Mouser Part Number 402-SLG59M309V
J3, J6: Conn_01x01; PinHeader_1x01_P2.54mm_Vertical; not fitted
JP3: SYNC; SolderJumper-2_P1.3mm_Bridged_Pad1.0x1.5mm
JP4: PSM; SolderJumper-2_P1.3mm_Bridged_Pad1.0x1.5mm
L1: 2u2 10% (74479276222C); L_Wuerth_PMFI-201610
L2: CDRH124NP-6R8MC; Mouser Part Number 851-CDRH124NP-6R8MC
R4, R5: 100k 20%; R_0603_1608Metric_Pad0.98x0.95mm_HandSolder

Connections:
3V3: C7.1, IC3.1 (VOUT), IC3.10 (FB), IC5.1 (VDD), IC5.3 (D), J3.1 (Pin_1_1); also elsewhere on the board
5V: C8.1, C9.1 (+), C10.1 (+), IC4.13 (VOUT_1), IC4.14 (VOUT_2), IC4.15 (VOUT_3), J6.1 (Pin_1_1); also elsewhere on the board
/EN_5V: IC4.9 (EN), R4.1; also elsewhere on the board
/EN_SAM_3V3: IC5.2 (ON), R5.1; also elsewhere on the board
GND: C5.2, C6.2, C7.2, C8.2, C9.2 (-), C10.2 (-), C11.2, IC3.3 (GND_1), IC3.9 (GND_2), IC3.11 (GND_3), IC4.3 (PGND_1), IC4.4 (PGND_2), IC4.5 (PGND_3), IC4.7 (LBI), IC4.11 (GND), IC4.17 (EP), IC5.8 (GND), JP4.2 (B), R4.2, R5.2; also elsewhere on the board
unnamed: IC3.4 (LX1), L1.1
unnamed: IC3.2 (LX2), L1.2
unnamed: IC3.7 (PS), JP4.1 (A)
unnamed: IC4.1 (SW_1), IC4.2 (SW_2), L2.3, L2.4
unnamed: IC4.8 (SYNC), JP3.2 (B)
unnamed: C11.1, IC5.7 (CAP)
SAM_3V3: IC5.5 (S); also elsewhere on the board
VSYS: C5.1, C6.1, IC3.5 (VIN), IC3.6 (EN), IC3.8 (VINA), IC4.6 (VBAT), JP3.1 (A), L2.1, L2.2; also elsewhere on the board

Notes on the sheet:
LBI, LBO (low battery indicator) not used Power save mode disabled (SYNC to VBAT)
5V conversion
3V3 conversion
SAM 3V3 switch
Rise time 2.5ms
10u minimal spec.
Power save mode is ON
C values copied from Pico 2
For extra cap if necessary

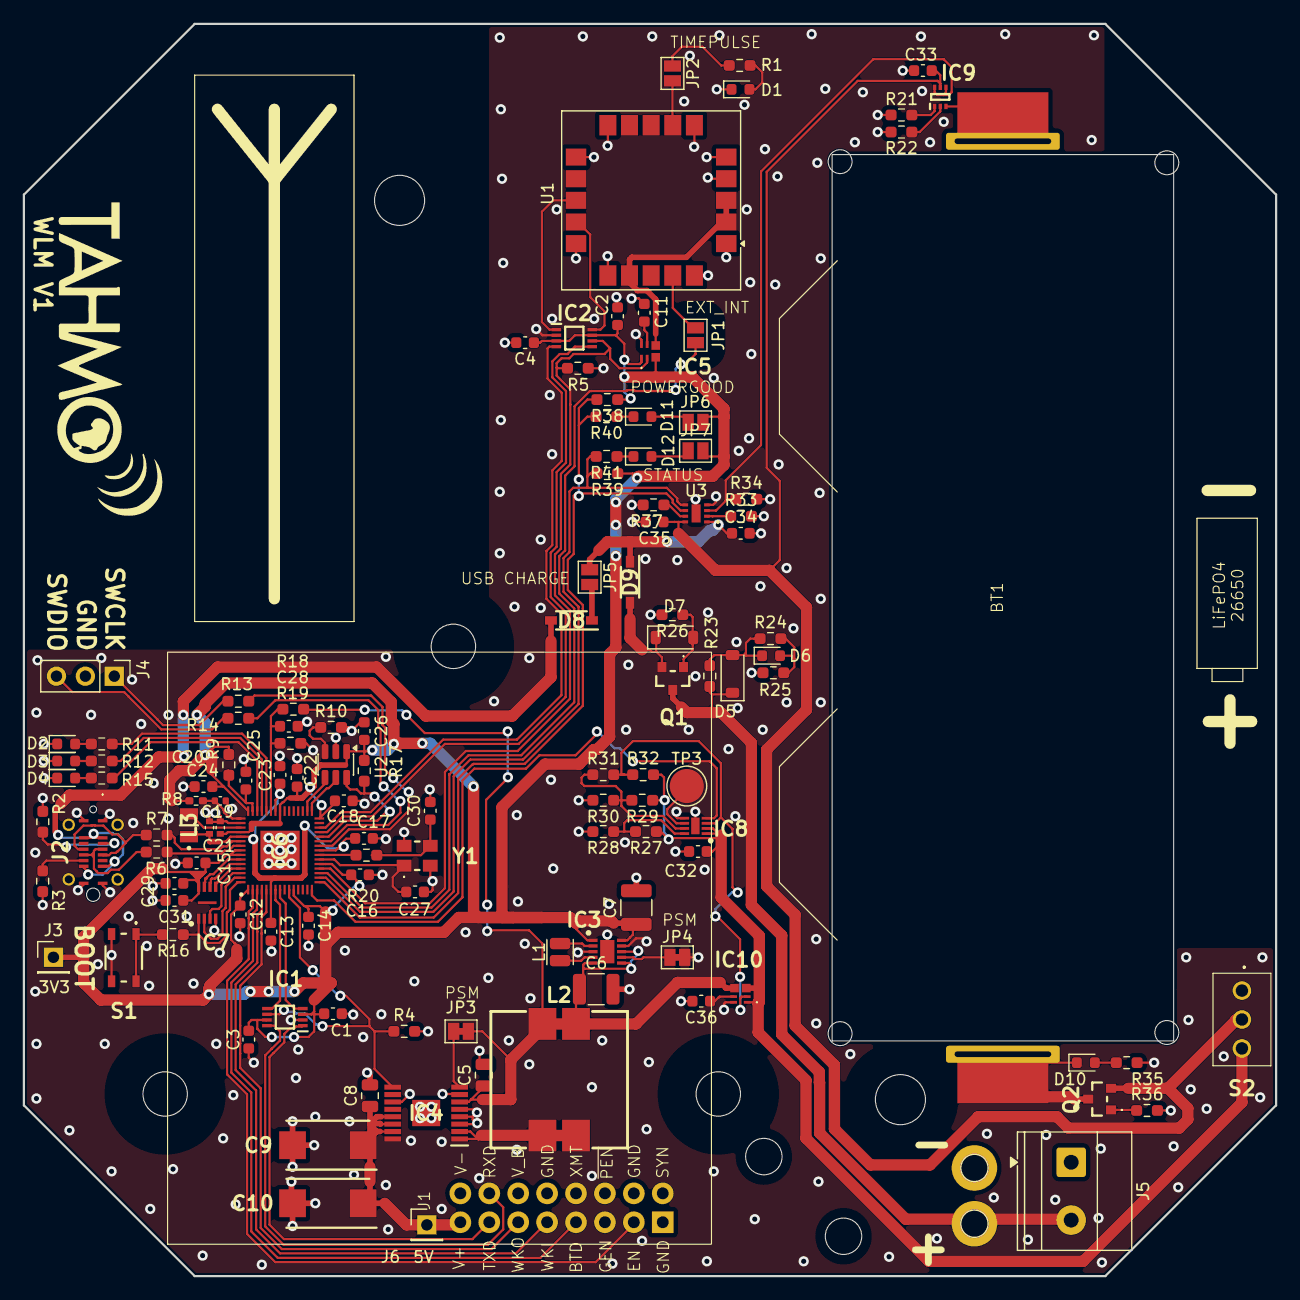
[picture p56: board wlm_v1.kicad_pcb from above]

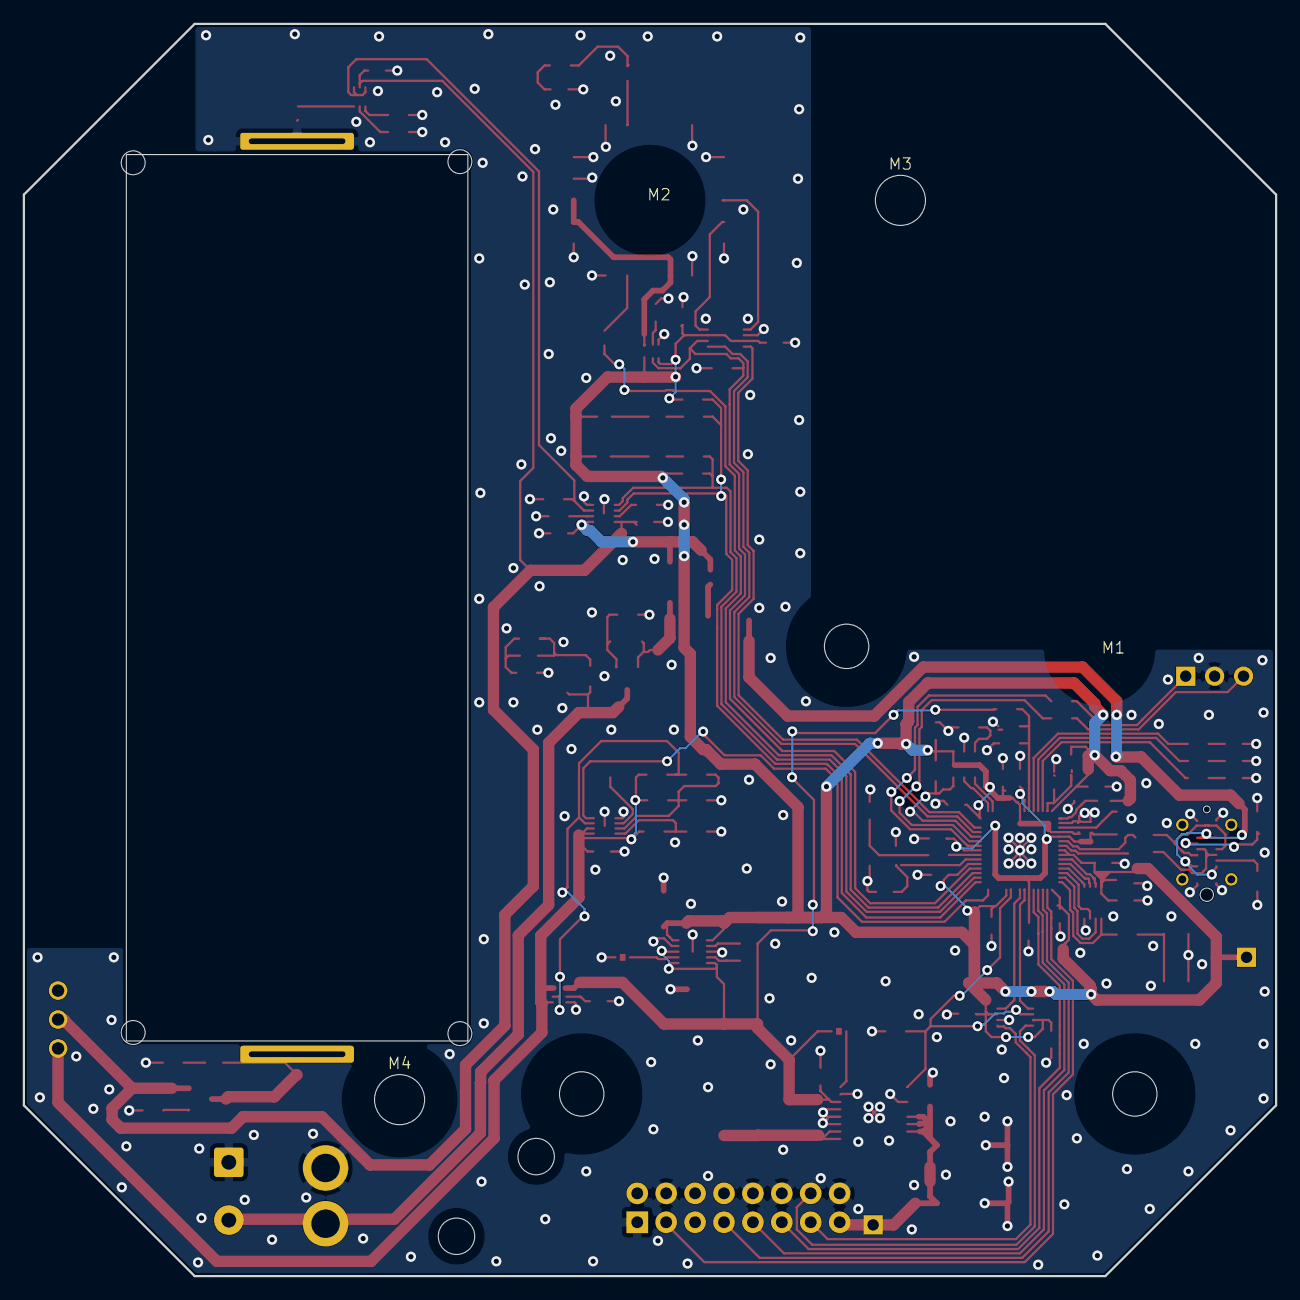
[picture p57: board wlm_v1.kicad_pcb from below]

Board: 2 copper layers, 110.0 x 110.0 mm, 137 parts (4 on the bottom side), 95 nets.

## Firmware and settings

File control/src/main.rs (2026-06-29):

//! This example test the RP Pico on board LED.
//!
//! It does not work with the RP Pico W board. See `blinky_wifi.rs`.

#![no_std]
#![no_main]

use defmt::*;
use embassy_executor::Spawner;
use embassy_rp::clocks::clk_sys_freq;
use embassy_rp::clocks::ClockConfig;
use embassy_rp::gpio;
use embassy_rp::gpio::Input;
use embassy_rp::uart;
use embassy_sync::mutex::Mutex;
use embassy_time::Duration;
use embassy_time::Instant;
use embassy_time::Timer;
use gpio::{Level, Output, Pull};
use embassy_rp::bind_interrupts;
use embassy_rp::uart::InterruptHandler as UARTInterruptHandler;
use embassy_rp::peripherals::{UART0, UART1, USB};
use embassy_sync::channel::Channel;
use embassy_sync::blocking_mutex::raw::CriticalSectionRawMutex;
use static_cell::StaticCell;
use embassy_rp::adc;
use embassy_rp::usb::{Driver, InterruptHandler};

use {defmt_rtt as _, panic_probe as _};

mod nmea;
mod math;
mod storage;
mod types;
mod measure;
mod compute;
mod control;
mod utils;
mod gnss;
mod comms;
mod rockblock;
mod realtime;
mod scheduler;
mod messages;
mod battery;
mod monitor;
mod usb;
mod interface;

use crate::battery::Battery;
use crate::comms::task_comms;
use crate::compute::task_compute;
use crate::control::task_control;
use crate::interface::Interface;
use crate::usb::usb_task;
use crate::interface::interface_task;
use crate::messages::{MeasureReqMsg, ComputeReqMsg, CommReqMsg, MonReqMsg, IntReqMsg, MeasureResMsg, ComputeResMsg, CommResMsg, MonResMsg, IntResMsg};
use crate::gnss::GNSSSensor;
use crate::measure::task_measure;
use crate::monitor::task_monitor;
use crate::rockblock::RockBlock9704;
use crate::storage::FlashStorage;

static MEASURE_REQUEST_CHANNEL: Channel<CriticalSectionRawMutex, MeasureReqMsg, 8> = Channel::new();
static COMPUTE_REQUEST_CHANNEL: Channel<CriticalSectionRawMutex, ComputeReqMsg, 8> = Channel::new();
static COMM_REQUEST_CHANNEL: Channel<CriticalSectionRawMutex, CommReqMsg, 8> = Channel::new();
static MONITOR_REQUEST_CHANNEL: Channel<CriticalSectionRawMutex, MonReqMsg, 8> = Channel::new();
static INTERFACE_REQUEST_CHANNEL: Channel<CriticalSectionRawMutex, IntReqMsg, 8> = Channel::new();
static MEASURE_RESPONSE_CHANNEL: Channel<CriticalSectionRawMutex, MeasureResMsg, 8> = Channel::new();
static COMPUTE_RESPONSE_CHANNEL: Channel<CriticalSectionRawMutex, ComputeResMsg, 8> = Channel::new();
static COMM_RESPONSE_CHANNEL: Channel<CriticalSectionRawMutex, CommResMsg, 8> = Channel::new();
static MONITOR_RESPONSE_CHANNEL: Channel<CriticalSectionRawMutex, MonResMsg, 8> = Channel::new();
static INTERFACE_RESPONSE_CHANNEL: Channel<CriticalSectionRawMutex, IntResMsg, 8> = Channel::new();


pub const GNSS_PRE_UART_BAUDRATE: u32 = 9_600;
pub const GNSS_POST_UART_BAUDRATE: u32 = 115_200;
pub const ROCKBLOCK_UART_BAUDRATE: u32 = 230_400;

bind_interrupts!(pub struct Irqs {
    UART0_IRQ  => UARTInterruptHandler<UART0>;
    UART1_IRQ  => UARTInterruptHandler<UART1>;
    ADC_IRQ_FIFO => adc::InterruptHandler;
    USBCTRL_IRQ => InterruptHandler<USB>;
});

// Program metadata for `picotool info`.
// This isn't needed, but it's recomended to have these minimal entries.
#[unsafe(link_section = ".bi_entries")]
#[used]
pub static PICOTOOL_ENTRIES: [embassy_rp::binary_info::EntryAddr; 4] = [
    embassy_rp::binary_info::rp_program_name!(c"GNSS_IR_Control"),
    embassy_rp::binary_info::rp_program_description!(
        c"This code for a PI Pico 2 controls the GNSS_IR sensor made by team Tahmo! "
    ),
    embassy_rp::binary_info::rp_cargo_version!(),
    embassy_rp::binary_info::rp_program_build_attribute!(),
];

type StorageType = Mutex<CriticalSectionRawMutex, Option<FlashStorage>>;
static STORAGE: StorageType = Mutex::new(None);

fn create_clock_config() -> ClockConfig {
    //USB is unstable below 50Mhz
    let result = ClockConfig::system_freq(50_000_000);

    if result.is_err() {
        error!("Failed to set system clock frequency");
    }

    result.unwrap()
}

#[embassy_executor::main]
async fn main(spawner: Spawner) {
    info!("[main] startup");
    // Init peripherals
    let mut config: embassy_rp::config::Config = Default::default();
    config.clocks = create_clock_config();
    let p = embassy_rp::init(config);
    let start = Instant::now();

    info!("[main] clock freq: {} MHz", clk_sys_freq() / 1_000_000);
    
    // USB
    let usb_driver = Driver::new(p.USB, Irqs);
    let usb_context = usb::UsbContext::new(usb_driver);
    let interface = Interface::new(usb_context.class);

    // Battery peripherals
    let pin_bat_low_bat = Input::new(p.PIN_11, Pull::Up);
    let pin_bat_bq_powergood = Input::new(p.PIN_12, Pull::None);
    let pin_bat_bq_status = Input::new(p.PIN_13, Pull::None);

    let adc: adc::Adc<'_, adc::Async> = adc::Adc::new(p.ADC, Irqs, adc::Config::default());
    let pin_bat_voltage: adc::Channel<'_> = adc::Channel::new_pin(p.PIN_26, Pull::None);

    //Temp sensor
    let pin_temp = adc::Channel::new_temp_sensor(p.ADC_TEMP_SENSOR);

    let battery = Battery::new(
        pin_bat_low_bat, 
        pin_bat_bq_powergood, 
        pin_bat_bq_status, 
        pin_bat_voltage, 
        pin_temp,
        adc);
    
    // LED peripherals
    let led_red: Output<'_> = Output::new(p.PIN_27, Level::Low);
    let led_green: Output<'_> = Output::new(p.PIN_28, Level::Low);
    let led_blue: Output<'_> = Output::new(p.PIN_29, Level::Low);

    // GNSS peripherals
    let mut gnss_uart_config = uart::Config::default();
    gnss_uart_config.baudrate = GNSS_PRE_UART_BAUDRATE;
    let gnss_uart = uart::Uart::new(p.UART0, p.PIN_16, p.PIN_17, Irqs, p.DMA_CH0, p.DMA_CH1, gnss_uart_config);
    let pin_gnss_power = Output::new(p.PIN_15, Level::Low);
    let mut gnss_sensor = GNSSSensor::new(gnss_uart, pin_gnss_power);

    // Rockblock pheripherals
    let mut config_uart_rockblock = uart::Config::default();
    config_uart_rockblock.baudrate = ROCKBLOCK_UART_BAUDRATE;
    let uart_rockblock = uart::Uart::new(p.UART1, p.PIN_4, p.PIN_5, Irqs, p.DMA_CH2, p.DMA_CH3, config_uart_rockblock);
    let pin_rockblock_power = Output::new(p.PIN_7, Level::Low);
    let pin_iridium_enable = Output::new(p.PIN_0, Level::Low);
    let pin_iridium_status = gpio::Input::new(p.PIN_1, gpio::Pull::None);
    let mut rockblock = RockBlock9704::new(
        uart_rockblock,
        pin_rockblock_power,
        pin_iridium_enable,
        pin_iridium_status
    );

    info!("[main] Turning off GNSS");
    gnss_sensor.sleep().await;

    info!("[main] Turning off RockBlock");
    rockblock.power_off().await;
    info!("[main] RockBlock powered off");

    // Storage peripheral
    let storage = FlashStorage::new(p.FLASH, false);
    {
        *(STORAGE.lock().await) = Some(storage);
    }

    // Watchdog peripherals
    let wdg_wake =  Input::new(p.PIN_19, gpio::Pull::Down);
    let wdg_done = Output::new(p.PIN_20, Level::Low);

    info!("[main] initialized peripherals");

    info!("[main] starting watchdog feeder task");
    let result = spawner.spawn(watchdog_feeder(wdg_wake, wdg_done));
    if result.is_err() {
        error!("Failed to spawn watchdog feeder task: {}", result.unwrap_err());
    }

    info!("[main] spawning tasks");

    let result = spawner.spawn(usb_task(usb_context.device));

    if result.is_err() {
        error!("Failed to spawn USB task: {}", result.unwrap_err());
    }

    let result = spawner.spawn(interface_task(
        &INTERFACE_REQUEST_CHANNEL,
        &INTERFACE_RESPONSE_CHANNEL,
        interface,
        &STORAGE));

    if result.is_err() {
        error!("Failed to spawn Interface task: {}", result.unwrap_err());
    }

    let result = spawner.spawn(task_measure(
        &MEASURE_REQUEST_CHANNEL,
        &MEASURE_RESPONSE_CHANNEL,
        &STORAGE, 
        gnss_sensor
    ));

    if result.is_err() {
        error!("Failed to spawn measure task: {}", result.unwrap_err());
    }
       
    let result = spawner.spawn(task_compute(
        &COMPUTE_REQUEST_CHANNEL, 
        &COMPUTE_RESPONSE_CHANNEL, 
        &STORAGE
    ));

    if result.is_err() {
        error!("Failed to spawn compute task: {}", result.unwrap_err());
    }

    let result = spawner.spawn(task_comms(
        &COMM_REQUEST_CHANNEL, 
        &COMM_RESPONSE_CHANNEL,
        &STORAGE,
        rockblock
    ));

    if result.is_err() {
        error!("Failed to spawn comms task: {}", result.unwrap_err());
    }

    let result = spawner.spawn(task_control(
        &MEASURE_REQUEST_CHANNEL,
        &COMPUTE_REQUEST_CHANNEL,
        &COMM_REQUEST_CHANNEL,
        &MONITOR_REQUEST_CHANNEL,
        &INTERFACE_REQUEST_CHANNEL,
        &MEASURE_RESPONSE_CHANNEL,
        &COMPUTE_RESPONSE_CHANNEL,
        &COMM_RESPONSE_CHANNEL, 
        &MONITOR_RESPONSE_CHANNEL,
        &INTERFACE_RESPONSE_CHANNEL,
        &STORAGE,
    ));

    if result.is_err() {
        error!("Failed to spawn control task: {}", result.unwrap_err());
    }

    let result = spawner.spawn(led_blink(led_red, led_green, led_blue));

    if result.is_err() {
        error!("Failed to spawn LED blink task: {}", result.unwrap_err());
    }

    let result = spawner.spawn(task_monitor(
        &MONITOR_REQUEST_CHANNEL, 
        &MONITOR_RESPONSE_CHANNEL, 
        battery)
    );

    if result.is_err() {
        error!("Failed to spawn Monitor task: {}", result.unwrap_err());
    }
    
    info!("[main] startup complete in {} ms", Instant::now().as_millis() - start.as_millis());
}

#[embassy_executor::task]
async fn led_blink(mut led_red: Output<'static>, mut led_green: Output<'static>, mut led_blue: Output<'static> ) {
    info!("[led_]: starting");
    let mut leds = [led_red, led_green, led_blue];

    for led in leds.iter_mut() {
        led.set_high();
        Timer::after_millis(333).await;
        led.set_low();
    }

    loop {
        Timer::after_millis(5000).await;
        leds[1].set_high();
        Timer::after_millis(25).await;
        leds[1].set_low();
    }
}

#[embassy_executor::task]
async fn watchdog_feeder(mut wake: Input<'static>, mut done: Output<'static>) {
    info!("[wdg_]: starting");
    done.set_low();

    loop {
        Timer::after(Duration::from_millis(1000)).await;
        done.set_high();
        Timer::after(Duration::from_millis(1000)).await;
        done.set_low();

        wake.wait_for_high().await;
        info!("[wdg_]: WAKE signal received from TPL5010");
    }
}

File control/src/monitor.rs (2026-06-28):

use embassy_sync::{blocking_mutex::raw::CriticalSectionRawMutex, channel::Channel};
use embassy_futures::select::{select3, Either3};
use defmt::info;
use embassy_time::{Duration, Instant, Timer};
use core::cmp::max;
use crate::{battery::{Battery, ChargeState}, messages::{MonReqMsg, MonResMsg}};

const ADC_POLL_INTERVAL: u64 = 30;
const CHARGE_POLL_INTERVAL: u64 = 30;

#[embassy_executor::task]
pub async fn task_monitor(
    channel_req: &'static Channel<CriticalSectionRawMutex, MonReqMsg, 8>,
    channel_res: &'static Channel<CriticalSectionRawMutex, MonResMsg, 8>,
    mut battery: Battery,
) {
    let mut battery_mv: f32 = 0.0;
    let mut chip_temp_c: f32 = 0.0;
    let mut next_adc_measurement = Instant::now();

    let mut charge_state_monitor = ChargeStateMonitor::new();
    let mut next_charge_poll = Instant::now();

    info!("[moni] starting");
    
    loop {
        let mut adc_timer = Timer::at(next_adc_measurement);
        let mut charge_timer = Timer::at(next_charge_poll);

        let result = select3(
            &mut adc_timer,
            channel_req.receive(),
            &mut charge_timer
        ).await;
        match result {
            Either3::First(_) => {
                let start = Instant::now();
                match battery.get_battery_voltage().await {
                    Ok(volts) => {
                        battery_mv = calc_emwa(volts as f32, battery_mv, 0.02, 0.0, 4200.0);
                        info!("[moni] Battery millivolts {} (emwa {}) in {} ms", volts, battery_mv as u32, (Instant::now() - start).as_millis());
                        channel_res.send(MonResMsg::BatVoltSuccess { voltage: battery_mv as u32 }).await;
                    }
                    Err(_) => {
                        channel_res.send(MonResMsg::BatVoltFail).await;
                    }
                }

                let start = Instant::now();
                match battery.get_chip_temperature().await {
                    Ok(temp) => {
                        chip_temp_c = calc_emwa(temp, chip_temp_c, 0.02, -50.0, 85.0);
                        info!("[moni] Chip temperature: {} (emwa {}) in {} ms", temp, chip_temp_c, (Instant::now() - start).as_millis());
                        channel_res.send(MonResMsg::TempSuccess { temp_c: chip_temp_c }).await;
                    }
                    Err(_) => {
                        channel_res.send(MonResMsg::TempFail).await;
                    }
                }

                next_adc_measurement = next_adc_measurement.saturating_add(Duration::from_secs(ADC_POLL_INTERVAL));
            }
            Either3::Second(message) => {
                match message {
                    MonReqMsg::GetBatVolt => {
                        channel_res.send(MonResMsg::BatVoltSuccess { voltage: battery_mv as u32 }).await;
                    }
                    MonReqMsg::GetTemp => {
                        channel_res.send(MonResMsg::TempSuccess { temp_c: chip_temp_c }).await;
                    }
                    MonReqMsg::ResetChargeStateMonitor => {
                        charge_state_monitor.reset();
                    }

                }
            }
            Either3::Third(_) => {
                let (charge_state, bat_low) = battery.get_state().await;
                
                info!("[moni] Charge controller state: {:?}", charge_state);
                charge_state_monitor.set_state(charge_state);

                let statefraction = charge_state_monitor.get_fraction();
                channel_res.send(MonResMsg::ChargeState { fraction: statefraction, bat_low: bat_low }).await;

                let (a,b,c,d) = unpack_fractions(statefraction);
                info!(
                    "[moni] ChargeState fraction bytes: Fault: {:?}, NoInput: {:?}, Charging: {:?}, Standby: {:?}",
                    a, b, c, d
                );
                info!("[moni] Battery low: {:?}", bat_low);

                next_charge_poll = next_charge_poll.saturating_add(Duration::from_secs(CHARGE_POLL_INTERVAL));
            }
        }
    }
}

fn calc_emwa(now: f32, previous: f32, k: f32, min: f32, max: f32) -> f32 {
    if now <= min {
        previous
    } else if now >= max {
        previous
    } else if previous == 0.0 {
        now
    } else {
        now * k + previous * (1.0-k)
    }
}

struct ChargeStateMonitor {
    time_fault: u64,
    time_noinput: u64,
    time_charging: u64,
    time_standby: u64,

    last_time: Instant,
    current_state: ChargeState,
}

impl ChargeStateMonitor {
    pub fn new () -> Self{
        Self {
            time_fault: 0,
            time_noinput: 0,
            time_charging: 0,
            time_standby: 0,
            last_time: Instant::now(),
            current_state: ChargeState::Unknown
        }
    }

    pub fn reset(&mut self) {
        self.time_fault = 0;
        self.time_noinput = 0;
        self.time_charging = 0;
        self.time_standby = 0;

        self.last_time = Instant::now();
        self.current_state = ChargeState::Unknown;
    }

    pub fn set_state(&mut self, charge_state: ChargeState){
        let passed_time = (Instant::now() - self.last_time).as_secs();

        //Make sure that even <1 seconds in a state is represented
        match self.current_state {
            ChargeState::Unknown => {},
            ChargeState::Fault => self.time_fault = (self.time_fault+passed_time).max(1),
            ChargeState::NoInput => self.time_noinput = (self.time_noinput+passed_time).max(1),
            ChargeState::Charging => self.time_charging = (self.time_charging+passed_time).max(1),
            ChargeState::Standby => self.time_standby = (self.time_standby+passed_time).max(1),
        }

        self.current_state = charge_state;
        self.last_time = Instant::now();
    }

    pub fn get_state(&mut self) -> ChargeState {
        self.current_state
    }

    pub fn get_fraction(&mut self) -> [u8; 4] {
        // Function needs minimal changing to allow use of less bytes
        self.set_state(self.current_state);

        let max_time = max(
            max(self.time_fault, self.time_noinput),
            max(self.time_charging, self.time_standby),
        ) as f32;

        if max_time == 0.0 {
            return [0, 0, 0, 0];
        } 

        let a = self.time_fault as f32 / max_time;
        let b = self.time_noinput as f32 / max_time;
        let c = self.time_charging as f32 / max_time;
        let d = self.time_standby as f32 / max_time;

        let qa = non_std_ceil(a * 255.0).min(255.0) as u8;
        let qb = non_std_ceil(b * 255.0).min(255.0) as u8;
        let qc = non_std_ceil(c * 255.0).min(255.0) as u8;
        let qd = non_std_ceil(d * 255.0).min(255.0) as u8;

        [qa, qb, qc, qd]
    }

}

fn non_std_ceil(x: f32) -> f32 {
    let truncated = x as i32 as f32;

    if x == truncated {
        x
    } else if x > 0.0 {
        truncated + 1.0
    } else {
        truncated
    }
}
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

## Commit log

2026-02-17 Update pins to prototype
2026-05-19 Initial add of wlm_v1 pcb + documentation
    [100-00003-02_RevB.STEP, 10035726.step, 1106.stp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]
2026-06-25 Add get temperature from usb
2026-06-25 Add RGB leds
2026-06-28 Update chargestate
2026-06-29 case sensitive typo
2026-06-30 Add eurocircuits BOM
    [Eurocircuits_final_BOM.csv]

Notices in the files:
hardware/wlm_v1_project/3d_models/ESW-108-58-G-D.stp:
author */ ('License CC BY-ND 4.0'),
